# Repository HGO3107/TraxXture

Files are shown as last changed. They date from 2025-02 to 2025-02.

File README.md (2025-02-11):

# 🚀 TaxXture – The Tracker with Capturing Features
A tracking device with **remote interior capturing capabilty**

## 🔥 Features  
- **Real-time location tracking** – Get your vehicle’s location on demand  
- **Motion sensing & speed monitoring** – Know when your vehicle is on the move  
- **Battery Backup and health monitoring** – Keep track of power levels  
- **Remote interior capturing** – Snap image of your vehicle’s interior when needed  
- **Offline storage** – Data backup, even without an internet connection  
- **Reverse polarity protection** – To ensure the device does not get affected should incase the vehicle pollarity is mistakenly swapped  

## 🏗️ Project Structure  
📂 **Main Board** – The brains of the operation
📂 **Cam-Interconnect Board** – The bridge between the camera and the system  
📂 **Rendered Images** – Stunning visuals of the design  

## 🔧 Main Board – What's Inside?  
The **Main Board** packs all the essentials:  
✅ **Microcontroller, sensors, and actuator circuitry**  
✅ **LVDS driver/receiver port** – Ensures **3-5m** long-distance camera communication  

## 📸 Cam-Interconnect Board  
This board connects the camera to the system using:  
✅ **LVDS to SPI converter**  
✅ **Camera port connector**  

## 🚧 Disclaimer; Work in Progress (Status: **DRAFT** 🚀)  
Still some work to do, Below are what I could think of, you can pick it up from here if insterested:  

🔲 **Generate BOM & Fabrication files**  
🔲 **Review schematics & PCB layouts**  
🔲 **Complete the Cam-Interconnect Board:**  
   - PCB layout  
   - Electrical Rule Check (ERC) & Design Rule Check (DRC)  
🔲 **Finalize the enclosure design** (Done in FreeCAD but needs tweaks for connectors)  

## 📷 Main Board Images  

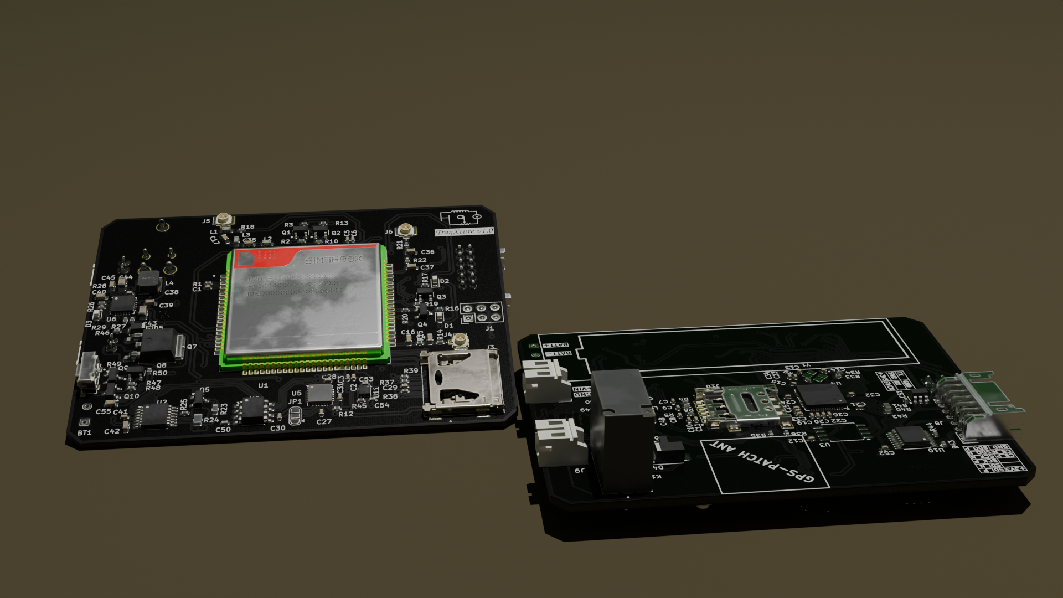
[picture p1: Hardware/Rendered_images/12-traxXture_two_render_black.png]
Main Board


[📄 View Documentation](Hardware/Main-Board/TraxXturE_board.pdf)

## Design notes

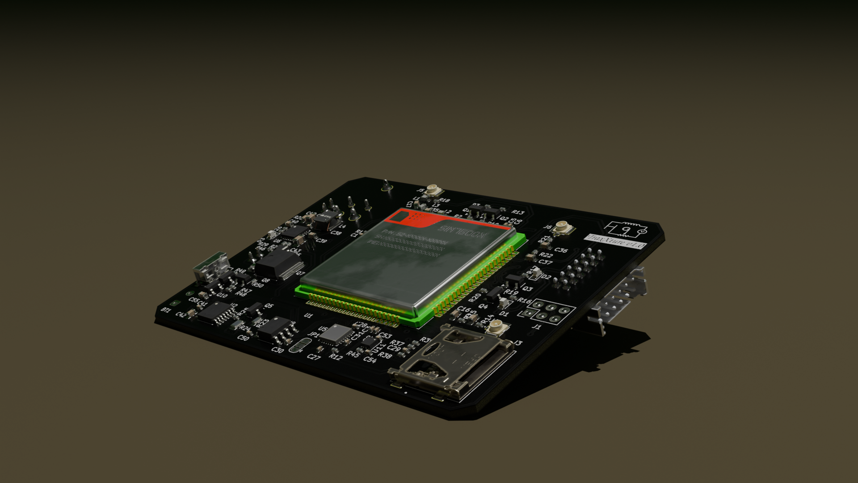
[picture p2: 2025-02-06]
Hardware/Rendered_images/10-traxXture_render_black.png

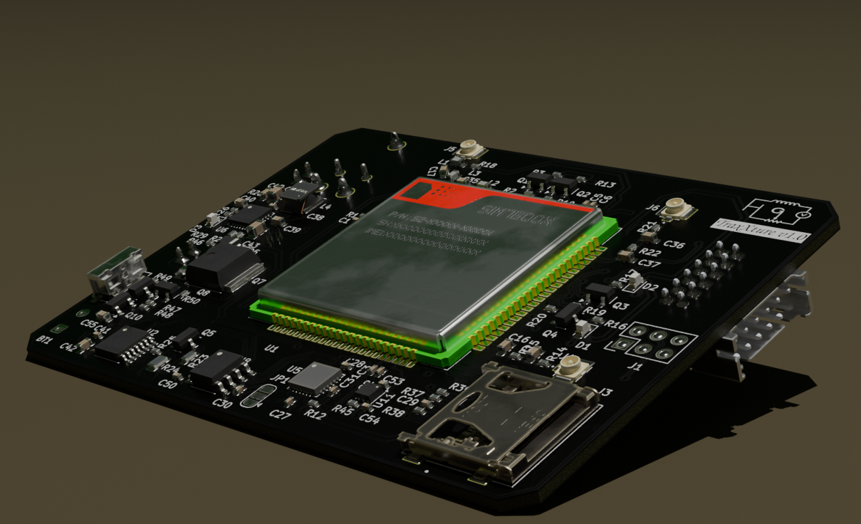
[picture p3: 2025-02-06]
Hardware/Rendered_images/11-traxXture_render_black_crop.png

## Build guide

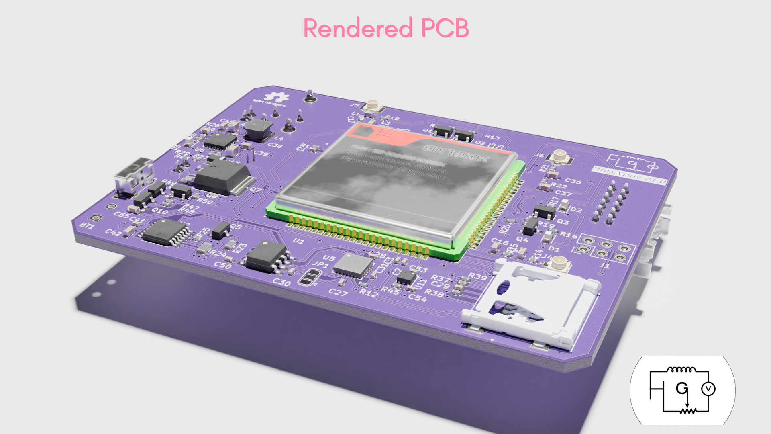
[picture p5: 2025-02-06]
Hardware/Rendered_images/Purple_soldermask.png

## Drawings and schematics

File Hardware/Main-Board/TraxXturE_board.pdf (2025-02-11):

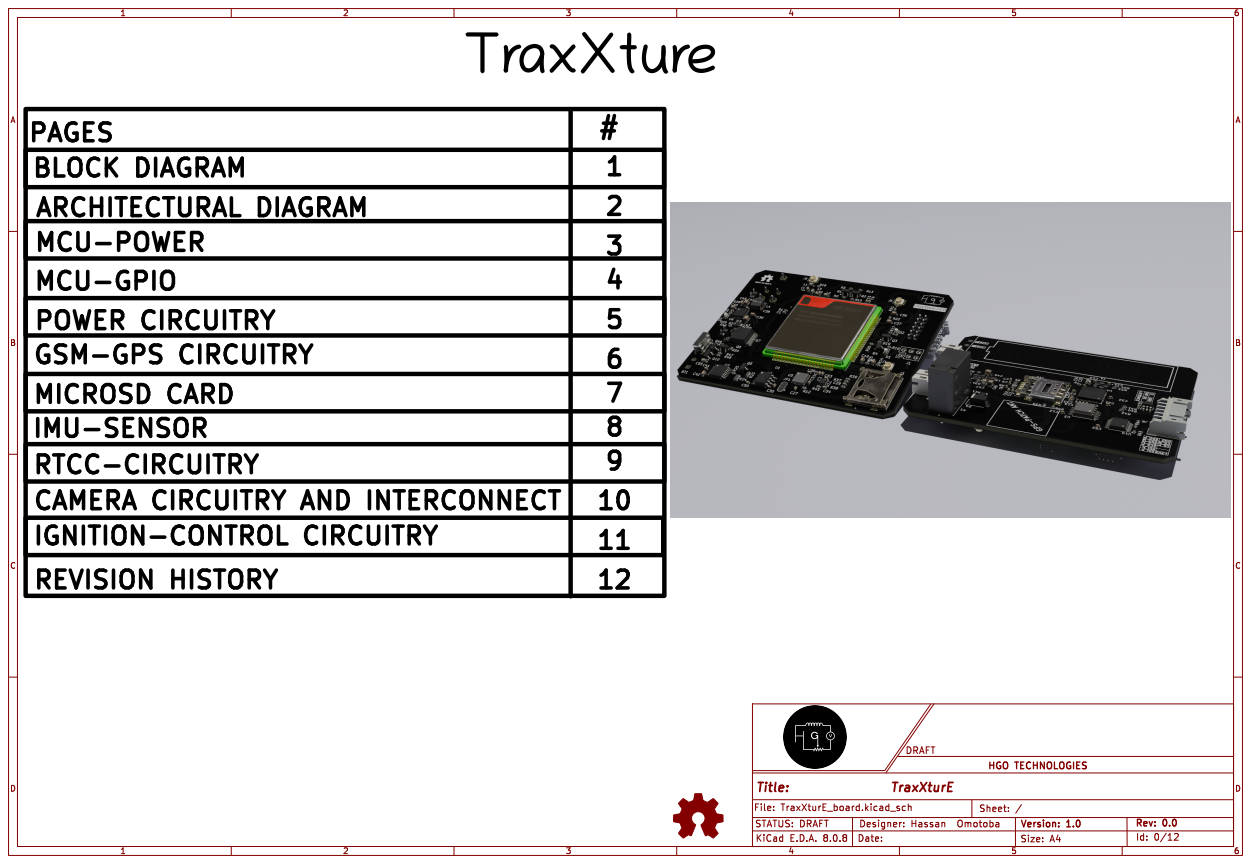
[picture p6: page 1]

MCU-GPIO
POWER CIRCUITRY
GSM-GPS CIRCUITRY | | 6
MICROSD CARD

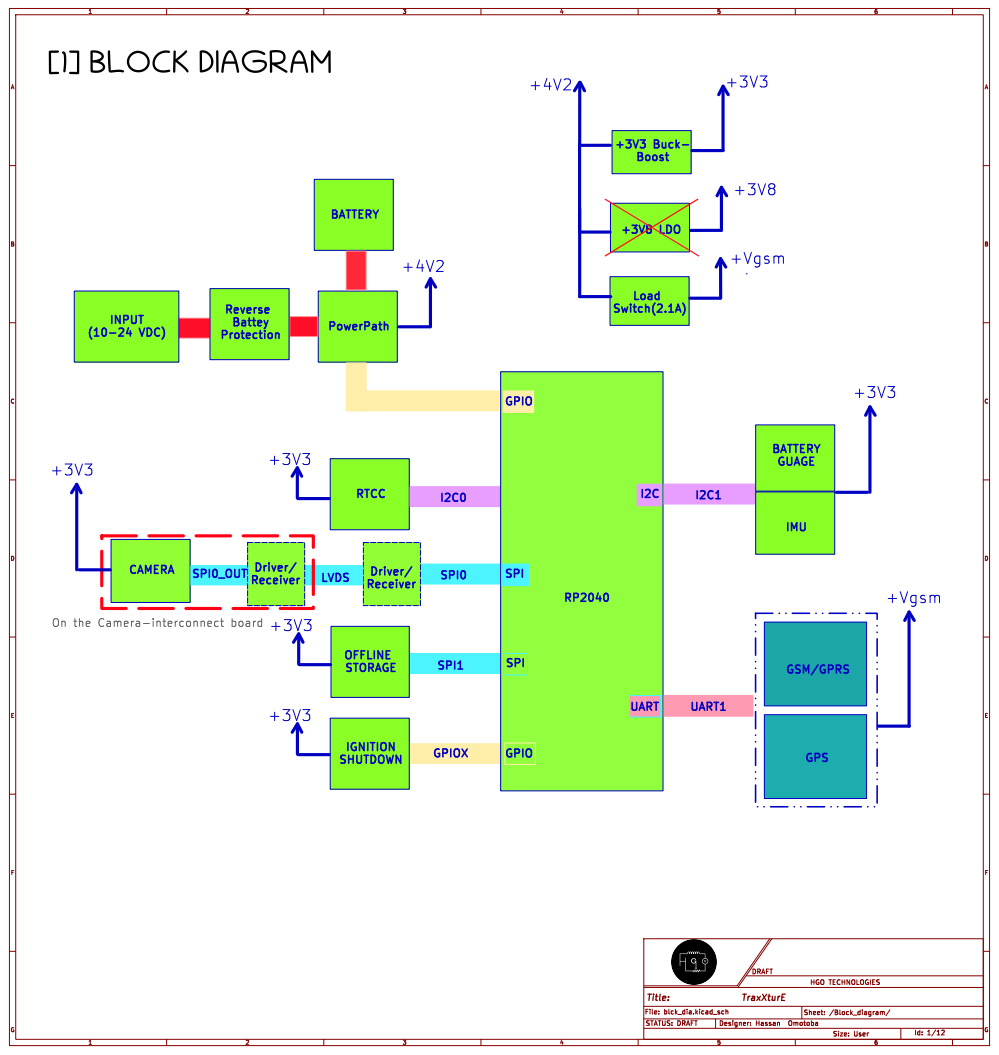
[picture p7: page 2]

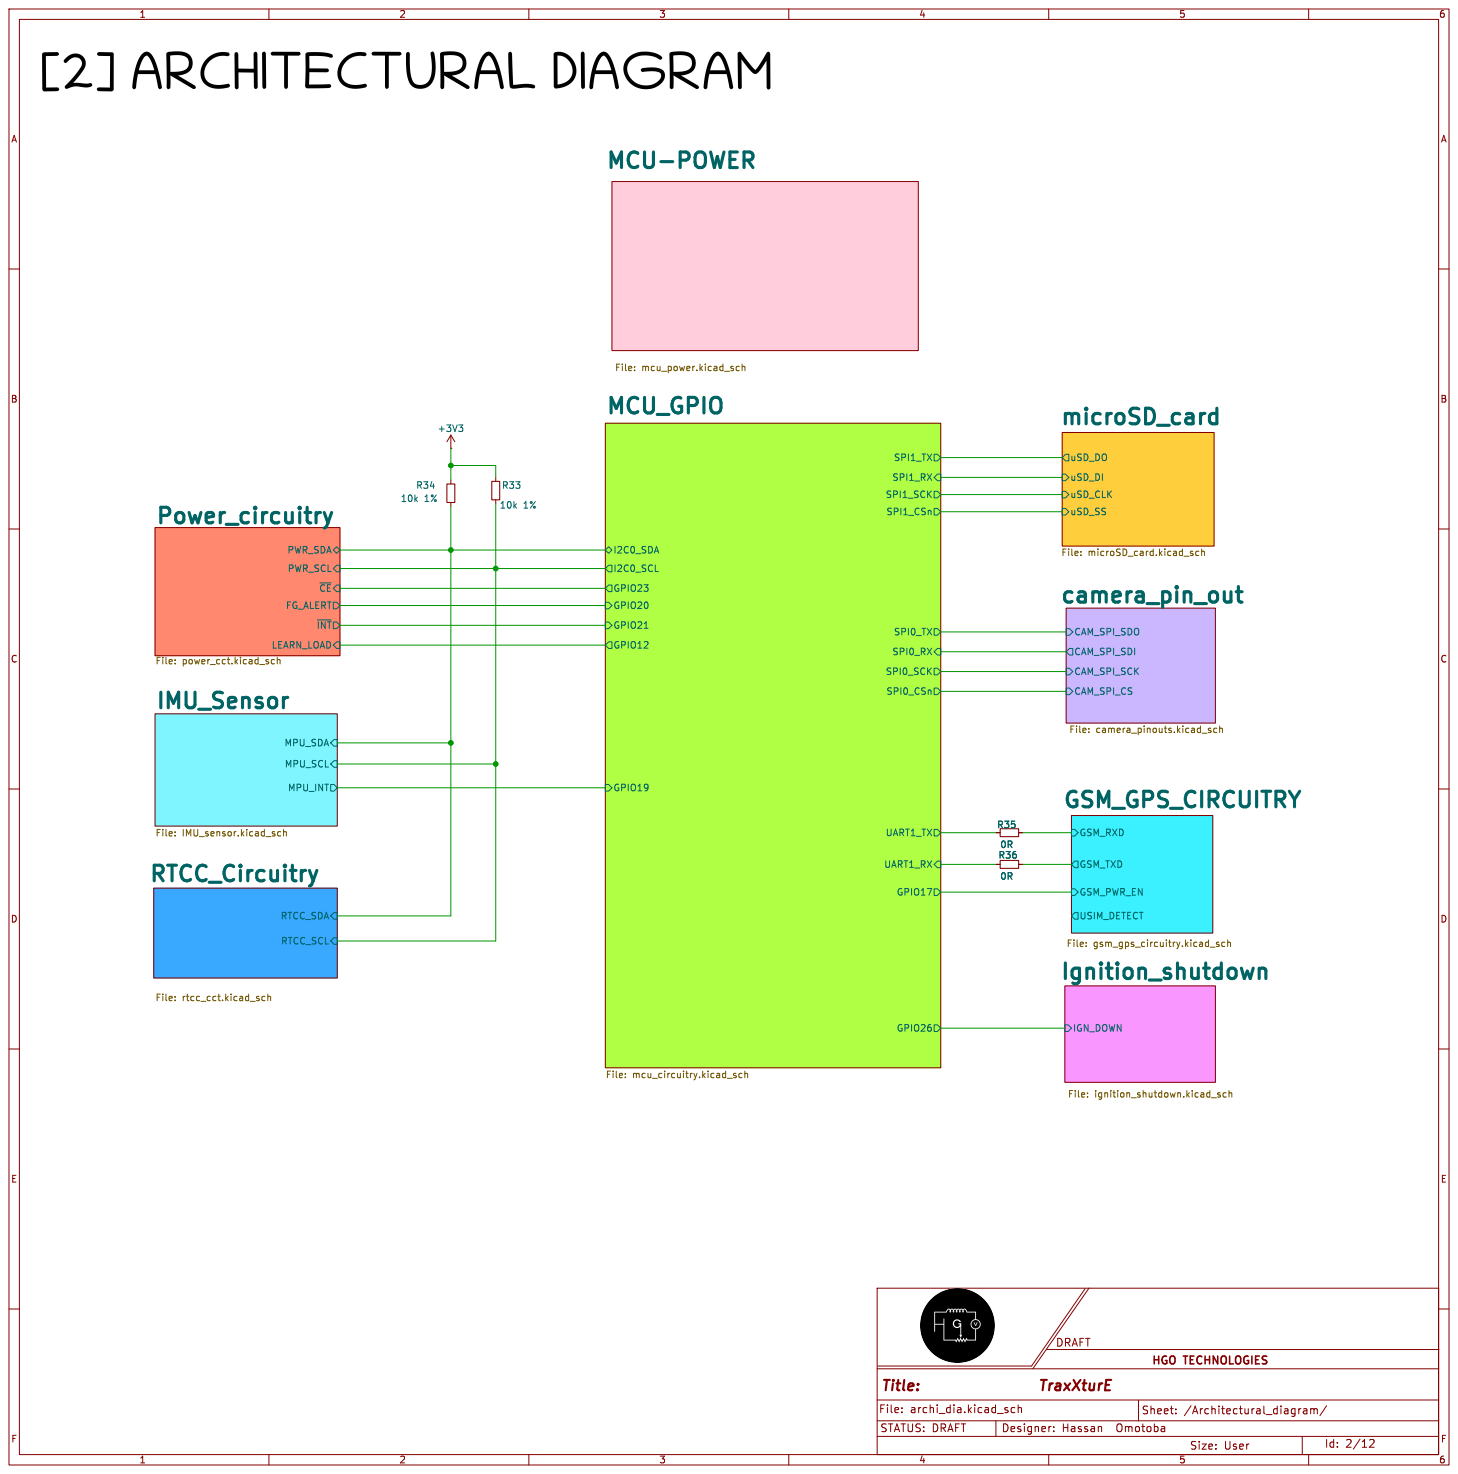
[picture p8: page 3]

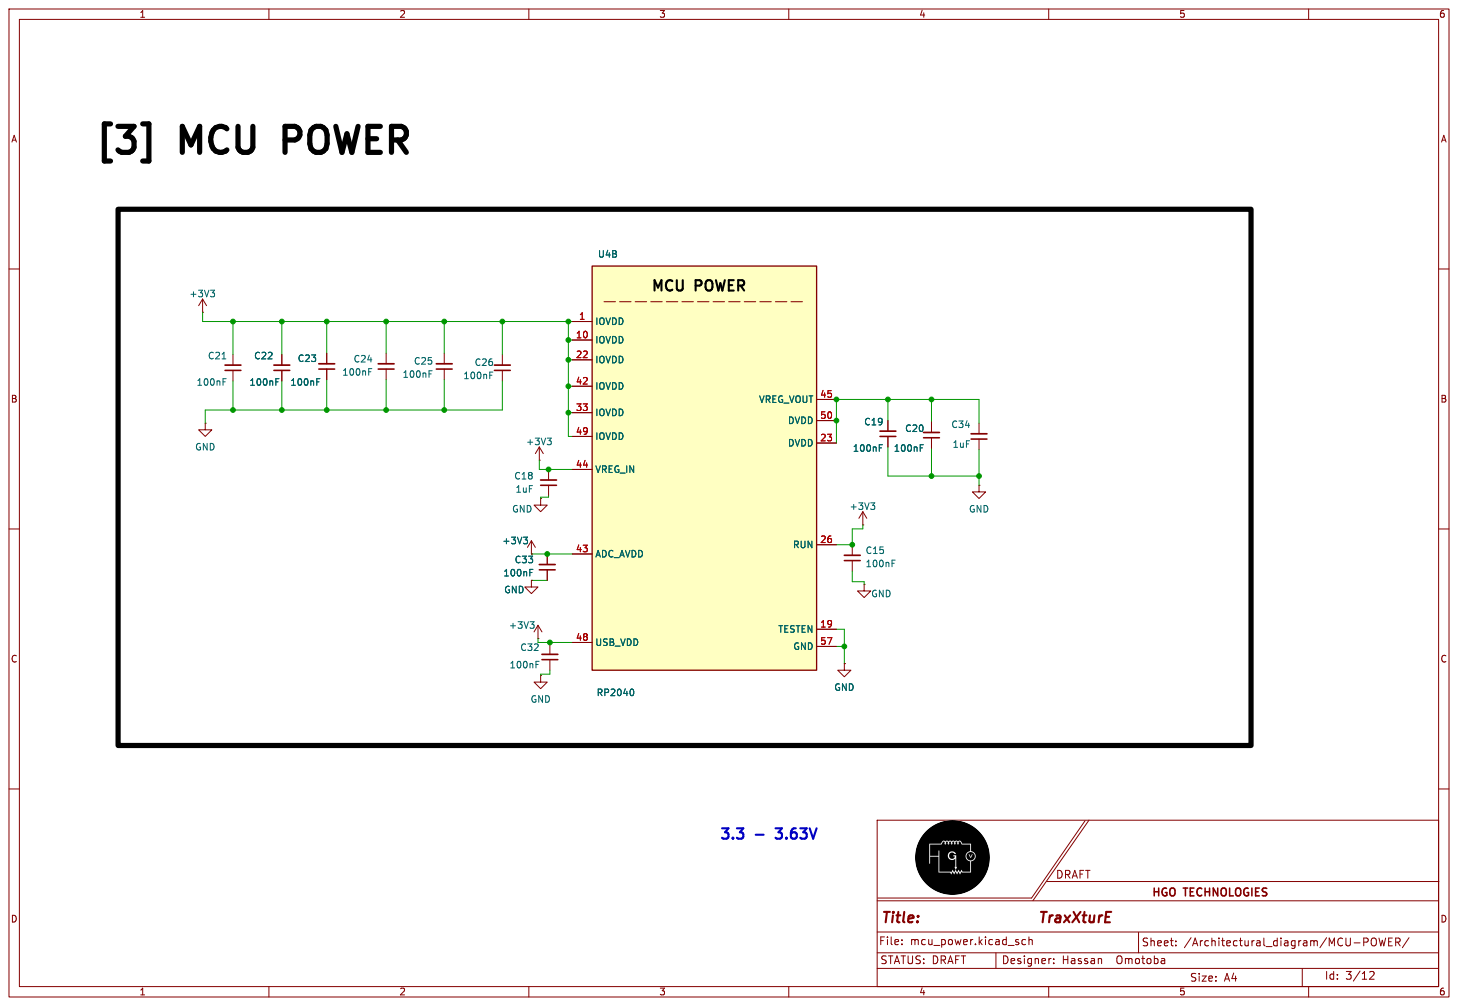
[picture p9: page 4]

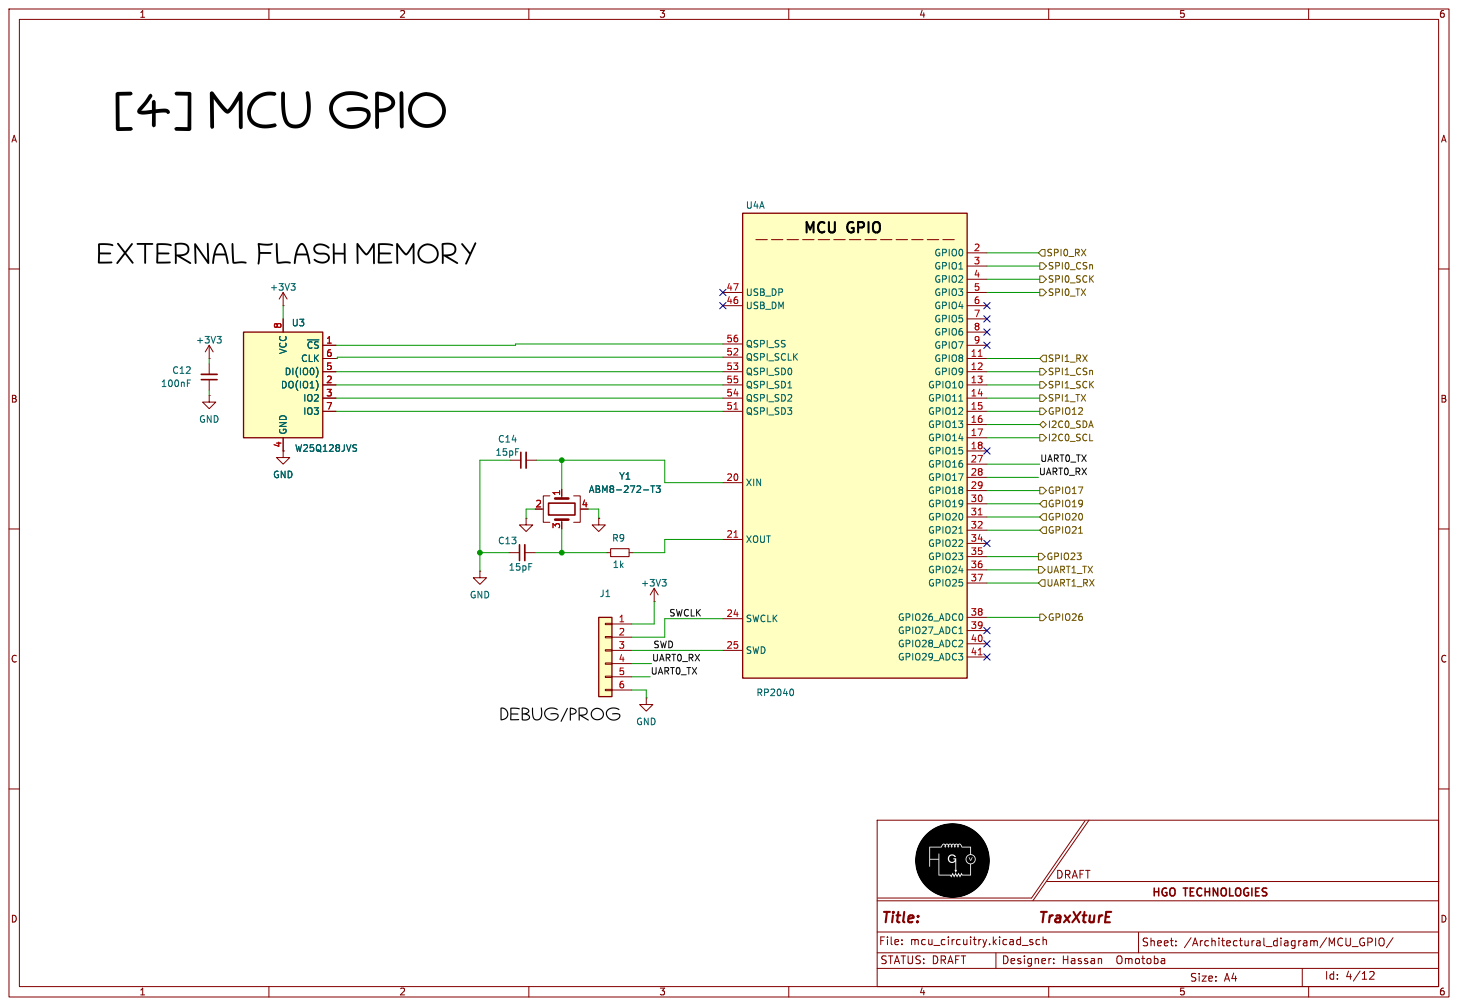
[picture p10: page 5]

SWCLK EXTERNAL FLASH MEMORY

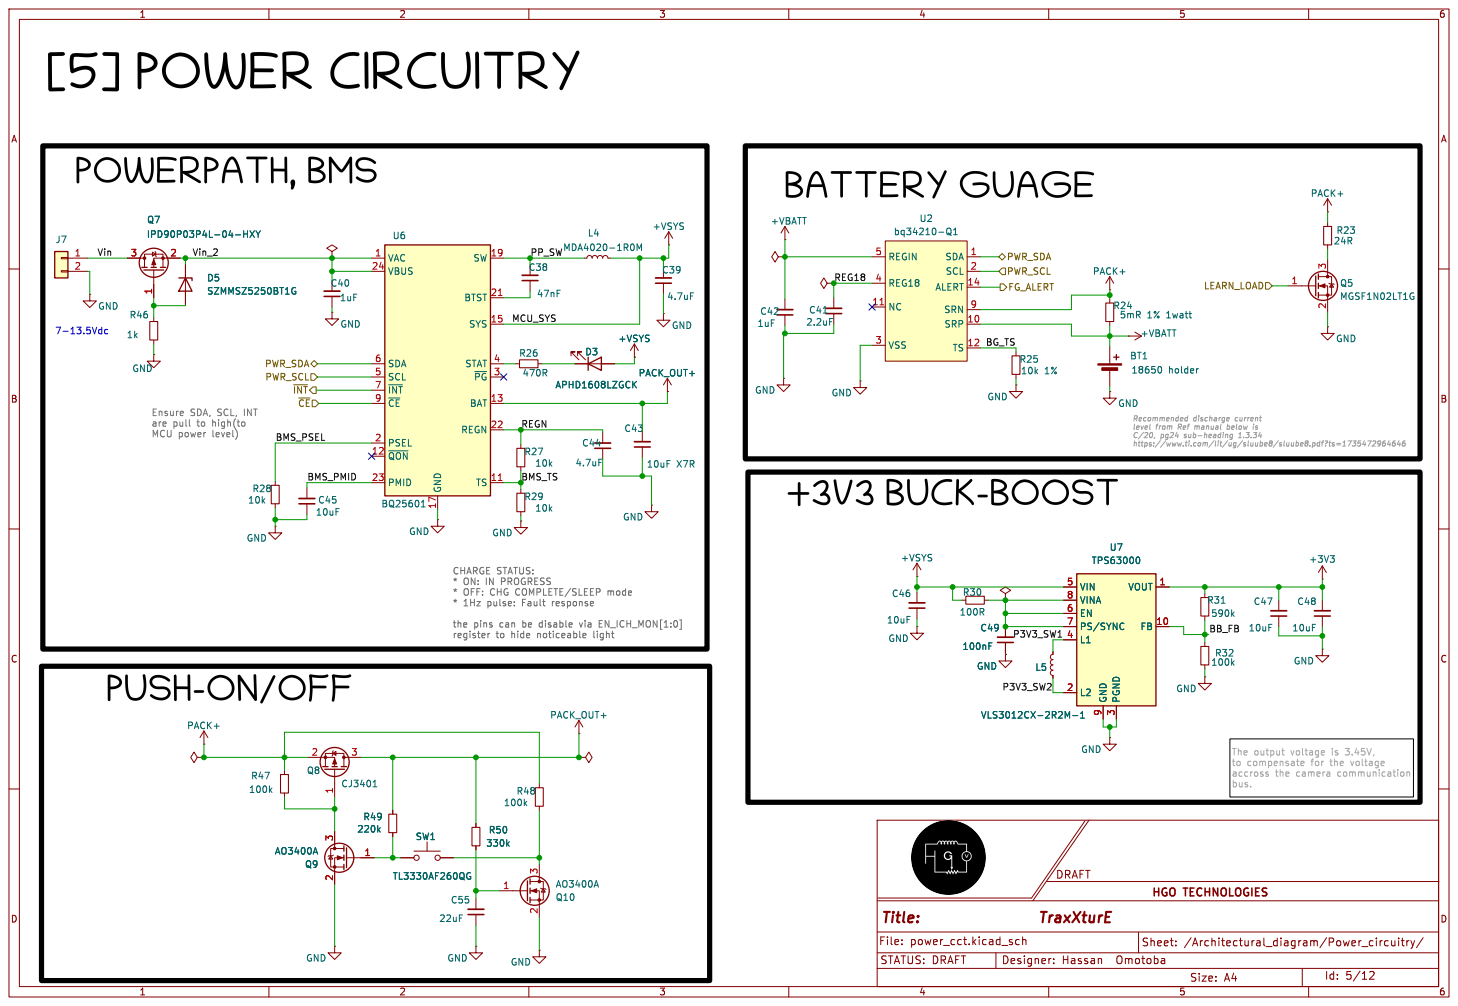
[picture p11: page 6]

https://www.ti.com/lit/ug/sluube8/sluube8.pdf?ts=1735472964646 [5] POWERCIRCUITRY
+VBATT R48

are pull to high(to MCU power level) 7-13.5Vdc POWERPATH,BMS

Ensure SDA, SCL, INT

CHARGE STATUS: * ON: IN PROGRESS
PACK_OUT+ GND

* OFF: CHG COMPLETE/SLEEP mode
* 1Hz pulse: Fault response

the pins can be disable via EN_ICH_MON[1:0]

bus. PUSH-ON/OFF

The output voltage is 3.45V,
accross the camera communication

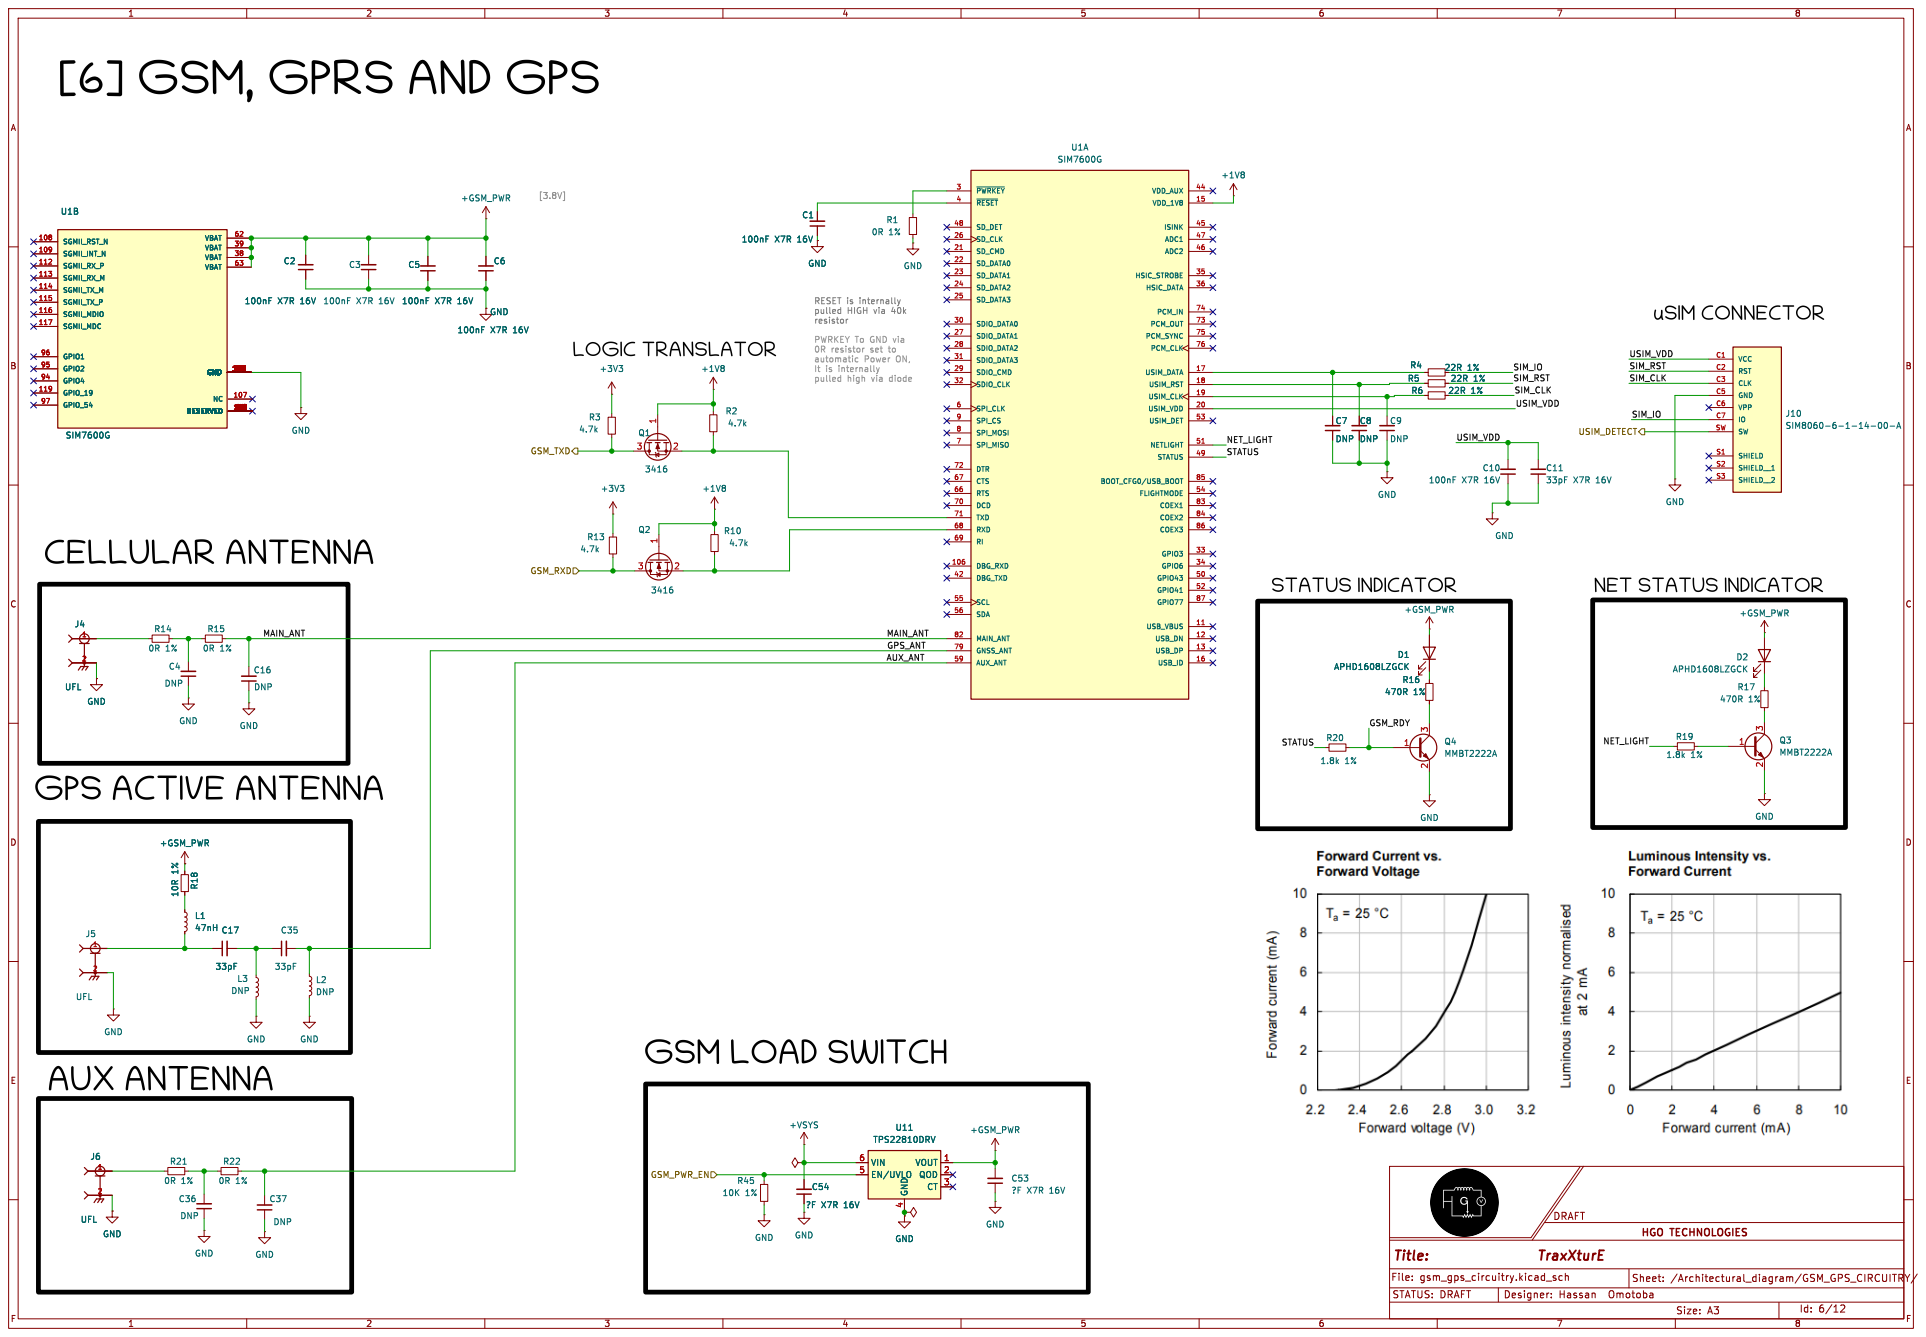
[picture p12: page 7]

pulled high via diode RESET is internally
pulled HIGH via 40k

PWRKEY To GND via
It is internally

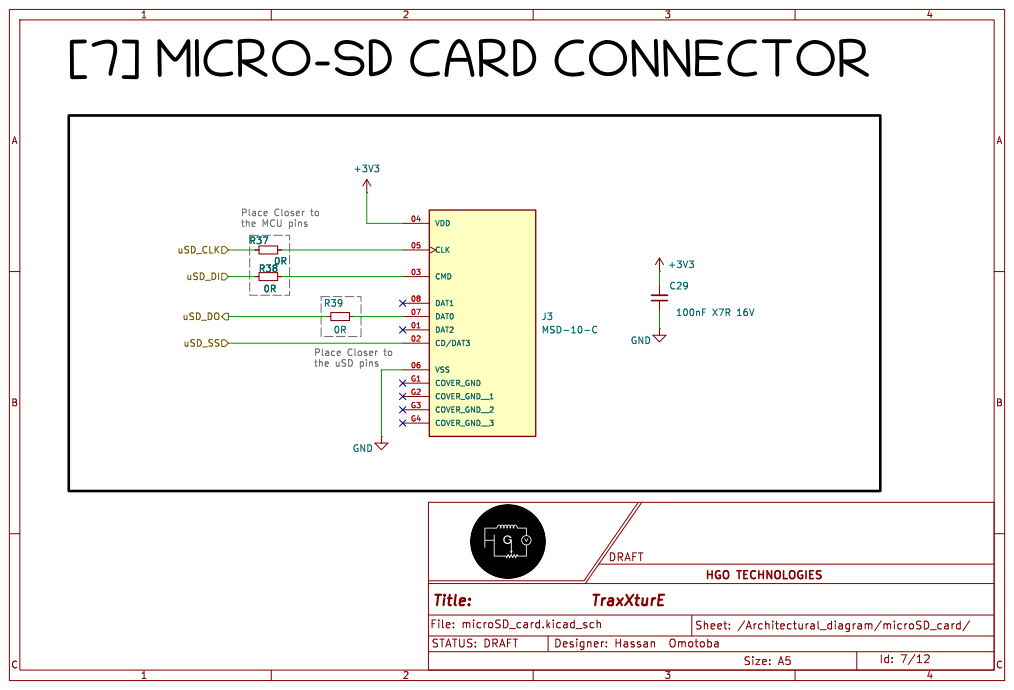
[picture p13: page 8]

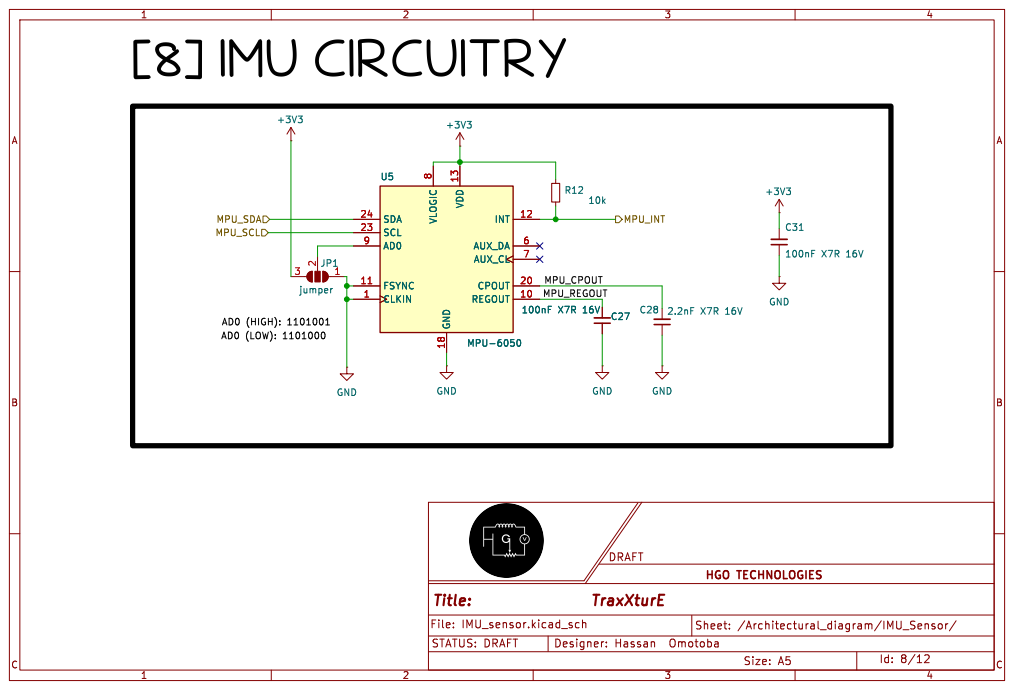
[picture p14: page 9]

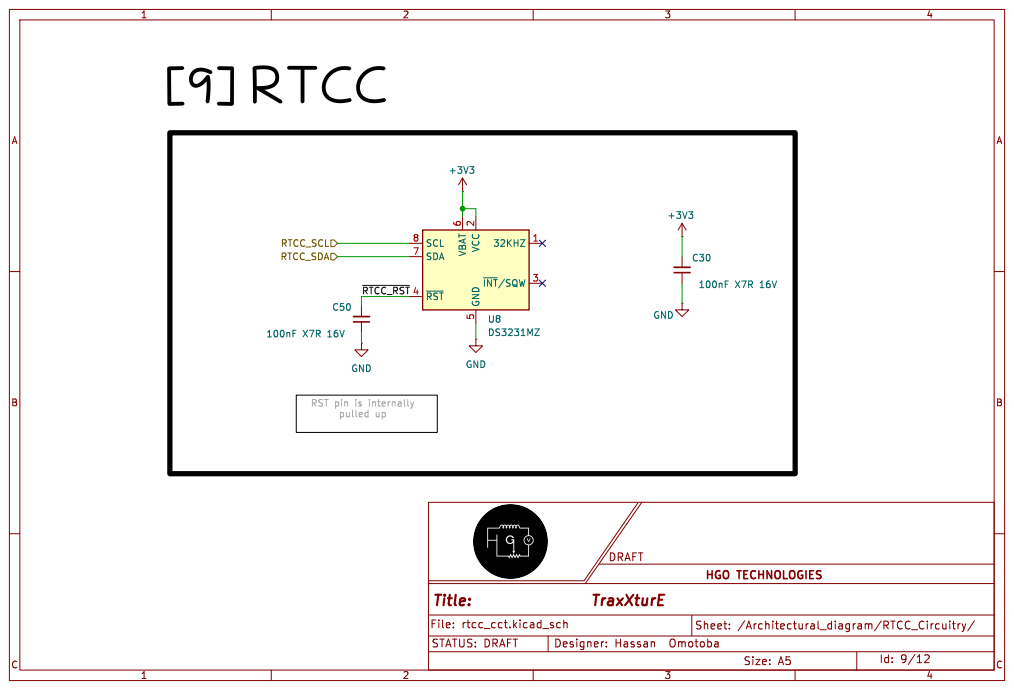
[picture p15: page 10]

RST pin is internally
pulled up

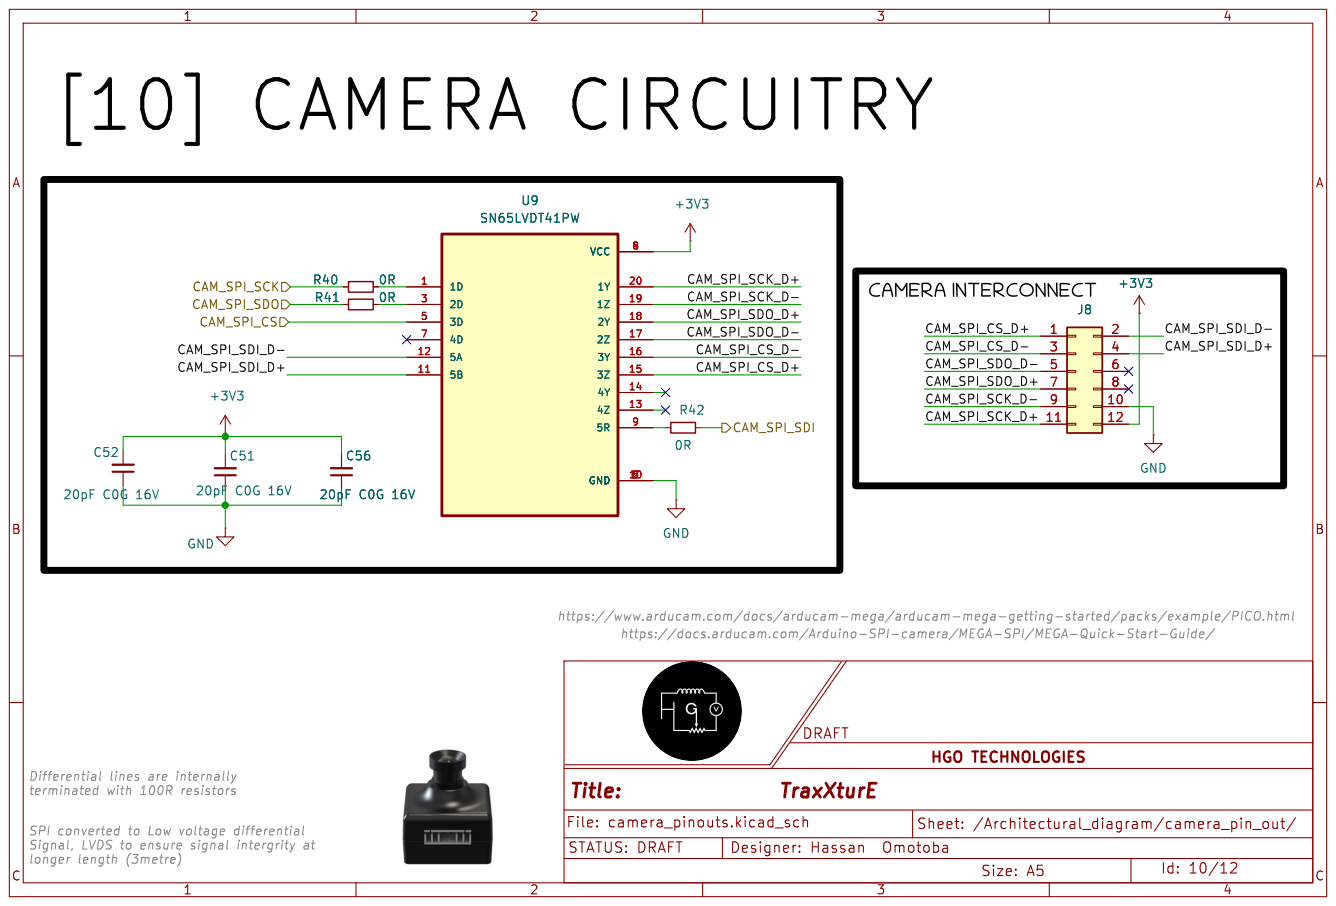
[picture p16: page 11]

https://www.arducam.com/docs/arducam-mega/arducam-mega-getting-started/packs/example/PICO.html

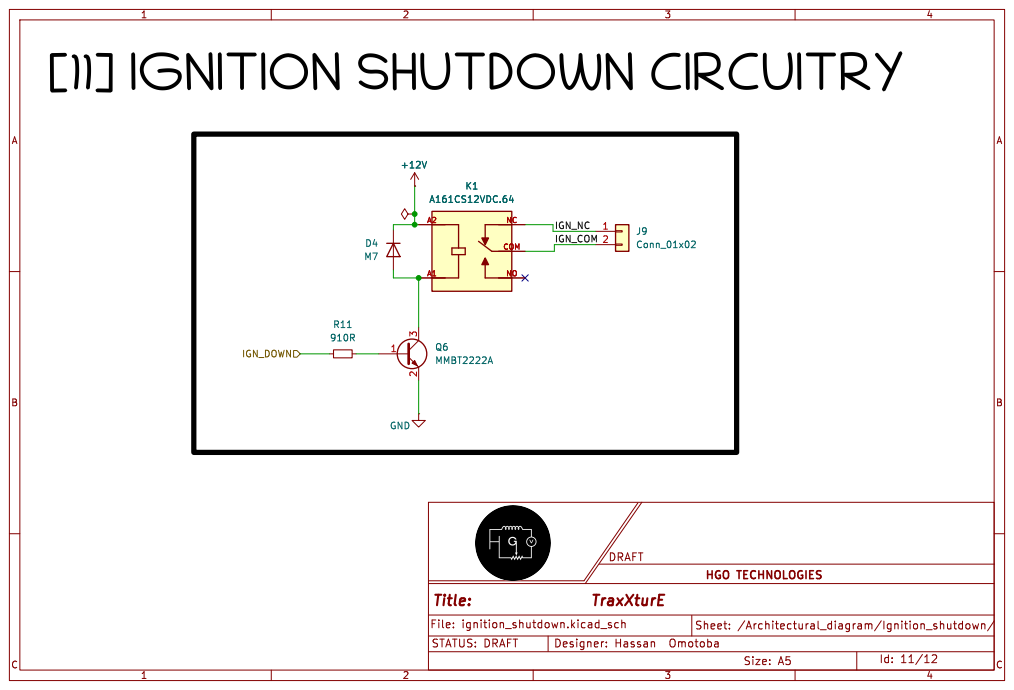
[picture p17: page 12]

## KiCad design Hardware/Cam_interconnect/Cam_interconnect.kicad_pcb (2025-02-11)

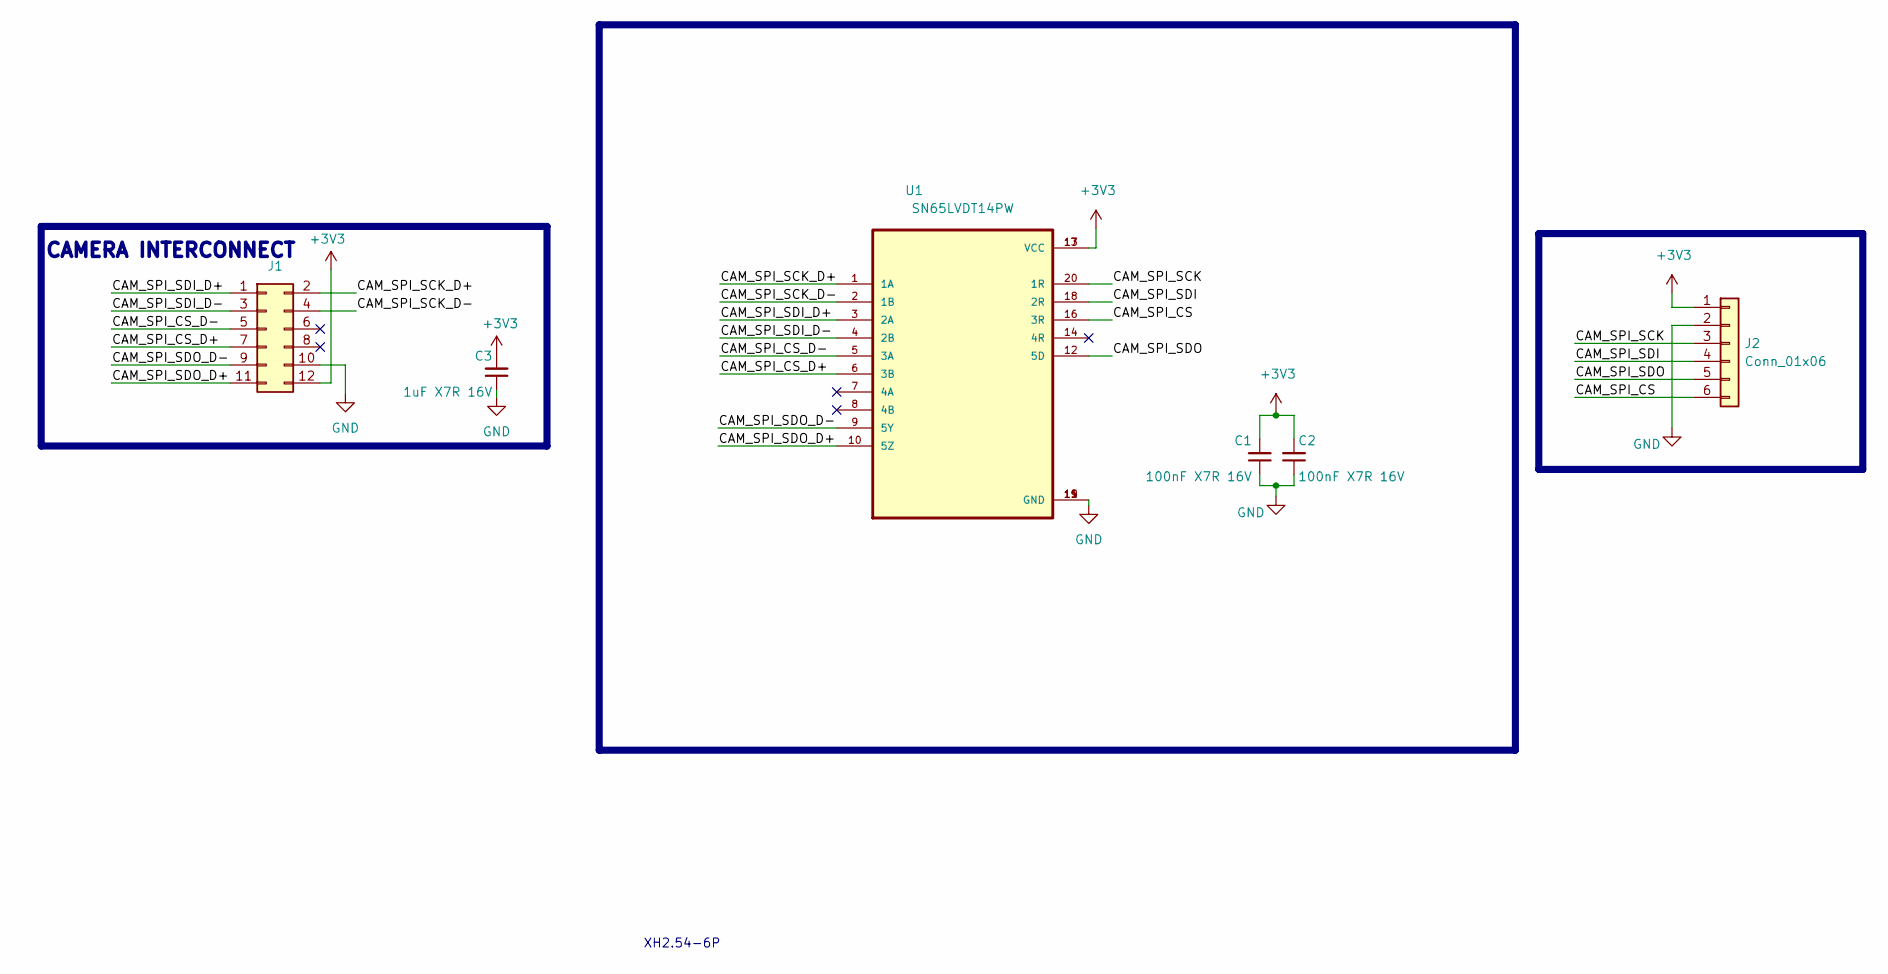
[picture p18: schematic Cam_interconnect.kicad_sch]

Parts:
C1, C2: 100nF X7R 16V; C_0402_1005Metric
C3: 1uF X7R 16V; C_0402_1005Metric
J1: Conn_02x06_Odd_Even; JST_PHD_S12B-PHDSS_2x06_P2.00mm_Horizontal
J2: Conn_01x06; PinSocket_1x06_P2.54mm_Vertical_SMD_Pin1Right
U1: SN65LVDT14PW; SOP65P640X120-20N

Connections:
+3V3: C1.2, C2.2, C3.2, J1.12, J2.1, U1.13 (VCC), U1.17 (VCC)
/CAM_SPI_CS: J2.6, U1.16 (3R)
/CAM_SPI_CS_D+: J1.7, U1.6 (3B)
/CAM_SPI_CS_D-: J1.5, U1.5 (3A)
/CAM_SPI_SCK: J2.3, U1.20 (1R)
/CAM_SPI_SCK_D+: J1.2, U1.1 (1A)
/CAM_SPI_SCK_D-: J1.4, U1.2 (1B)
/CAM_SPI_SDI: J2.4, U1.18 (2R)
/CAM_SPI_SDI_D+: J1.1, U1.3 (2A)
/CAM_SPI_SDI_D-: J1.3, U1.4 (2B)
/CAM_SPI_SDO: J2.5, U1.12 (5D)
/CAM_SPI_SDO_D+: J1.11, U1.10 (5Z)
/CAM_SPI_SDO_D-: J1.9, U1.9 (5Y)
GND: C1.1, C2.1, C3.1, J1.10, J2.2, U1.11 (GND), U1.15 (GND), U1.19 (GND)

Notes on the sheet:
XH2.54-6P
CAMERA INTERCONNECT

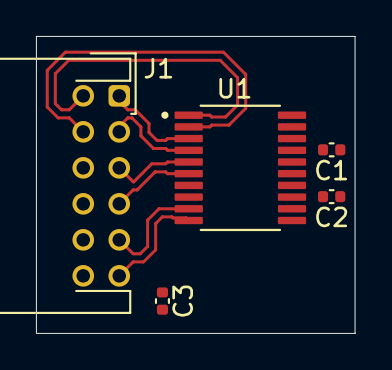
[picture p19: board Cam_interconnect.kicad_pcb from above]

Board: 4 copper layers, 17.7 x 16.5 mm, 6 parts (1 on the bottom side), 14 nets.

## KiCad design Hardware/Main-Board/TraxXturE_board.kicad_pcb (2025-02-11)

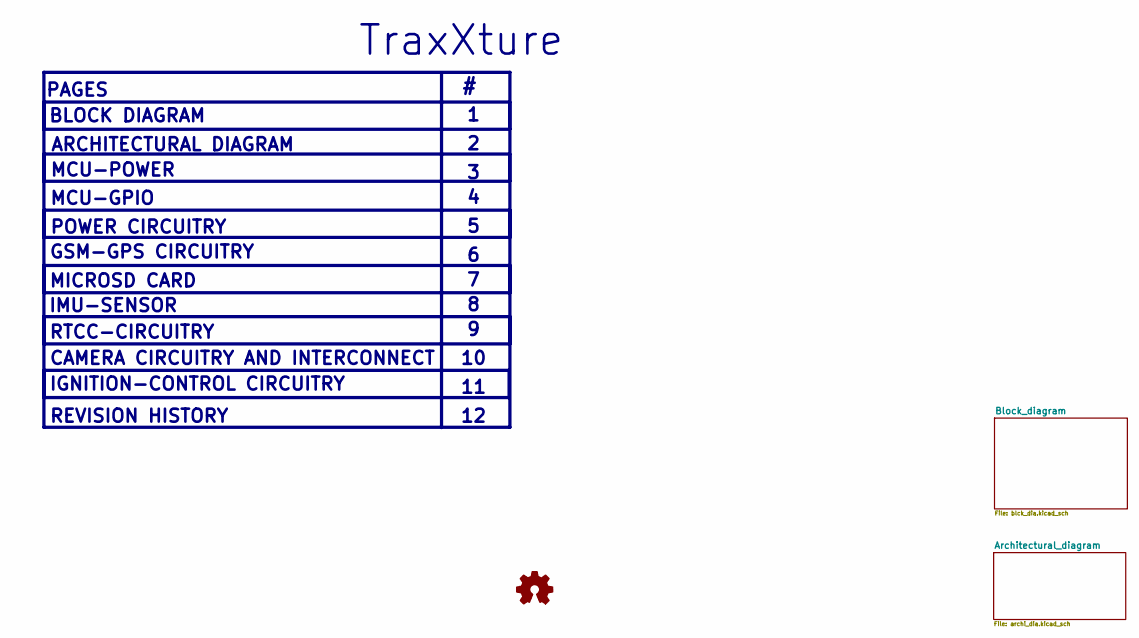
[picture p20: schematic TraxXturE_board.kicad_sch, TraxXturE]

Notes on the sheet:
IMU-SENSOR
MCU-POWER
MICROSD CARD
ARCHITECTURAL DIAGRAM
PAGES
RTCC-CIRCUITRY
CAMERA CIRCUITRY AND INTERCONNECT
BLOCK DIAGRAM
POWER CIRCUITRY
GSM-GPS CIRCUITRY
REVISION HISTORY
MCU-GPIO
IGNITION-CONTROL CIRCUITRY
TraxXture

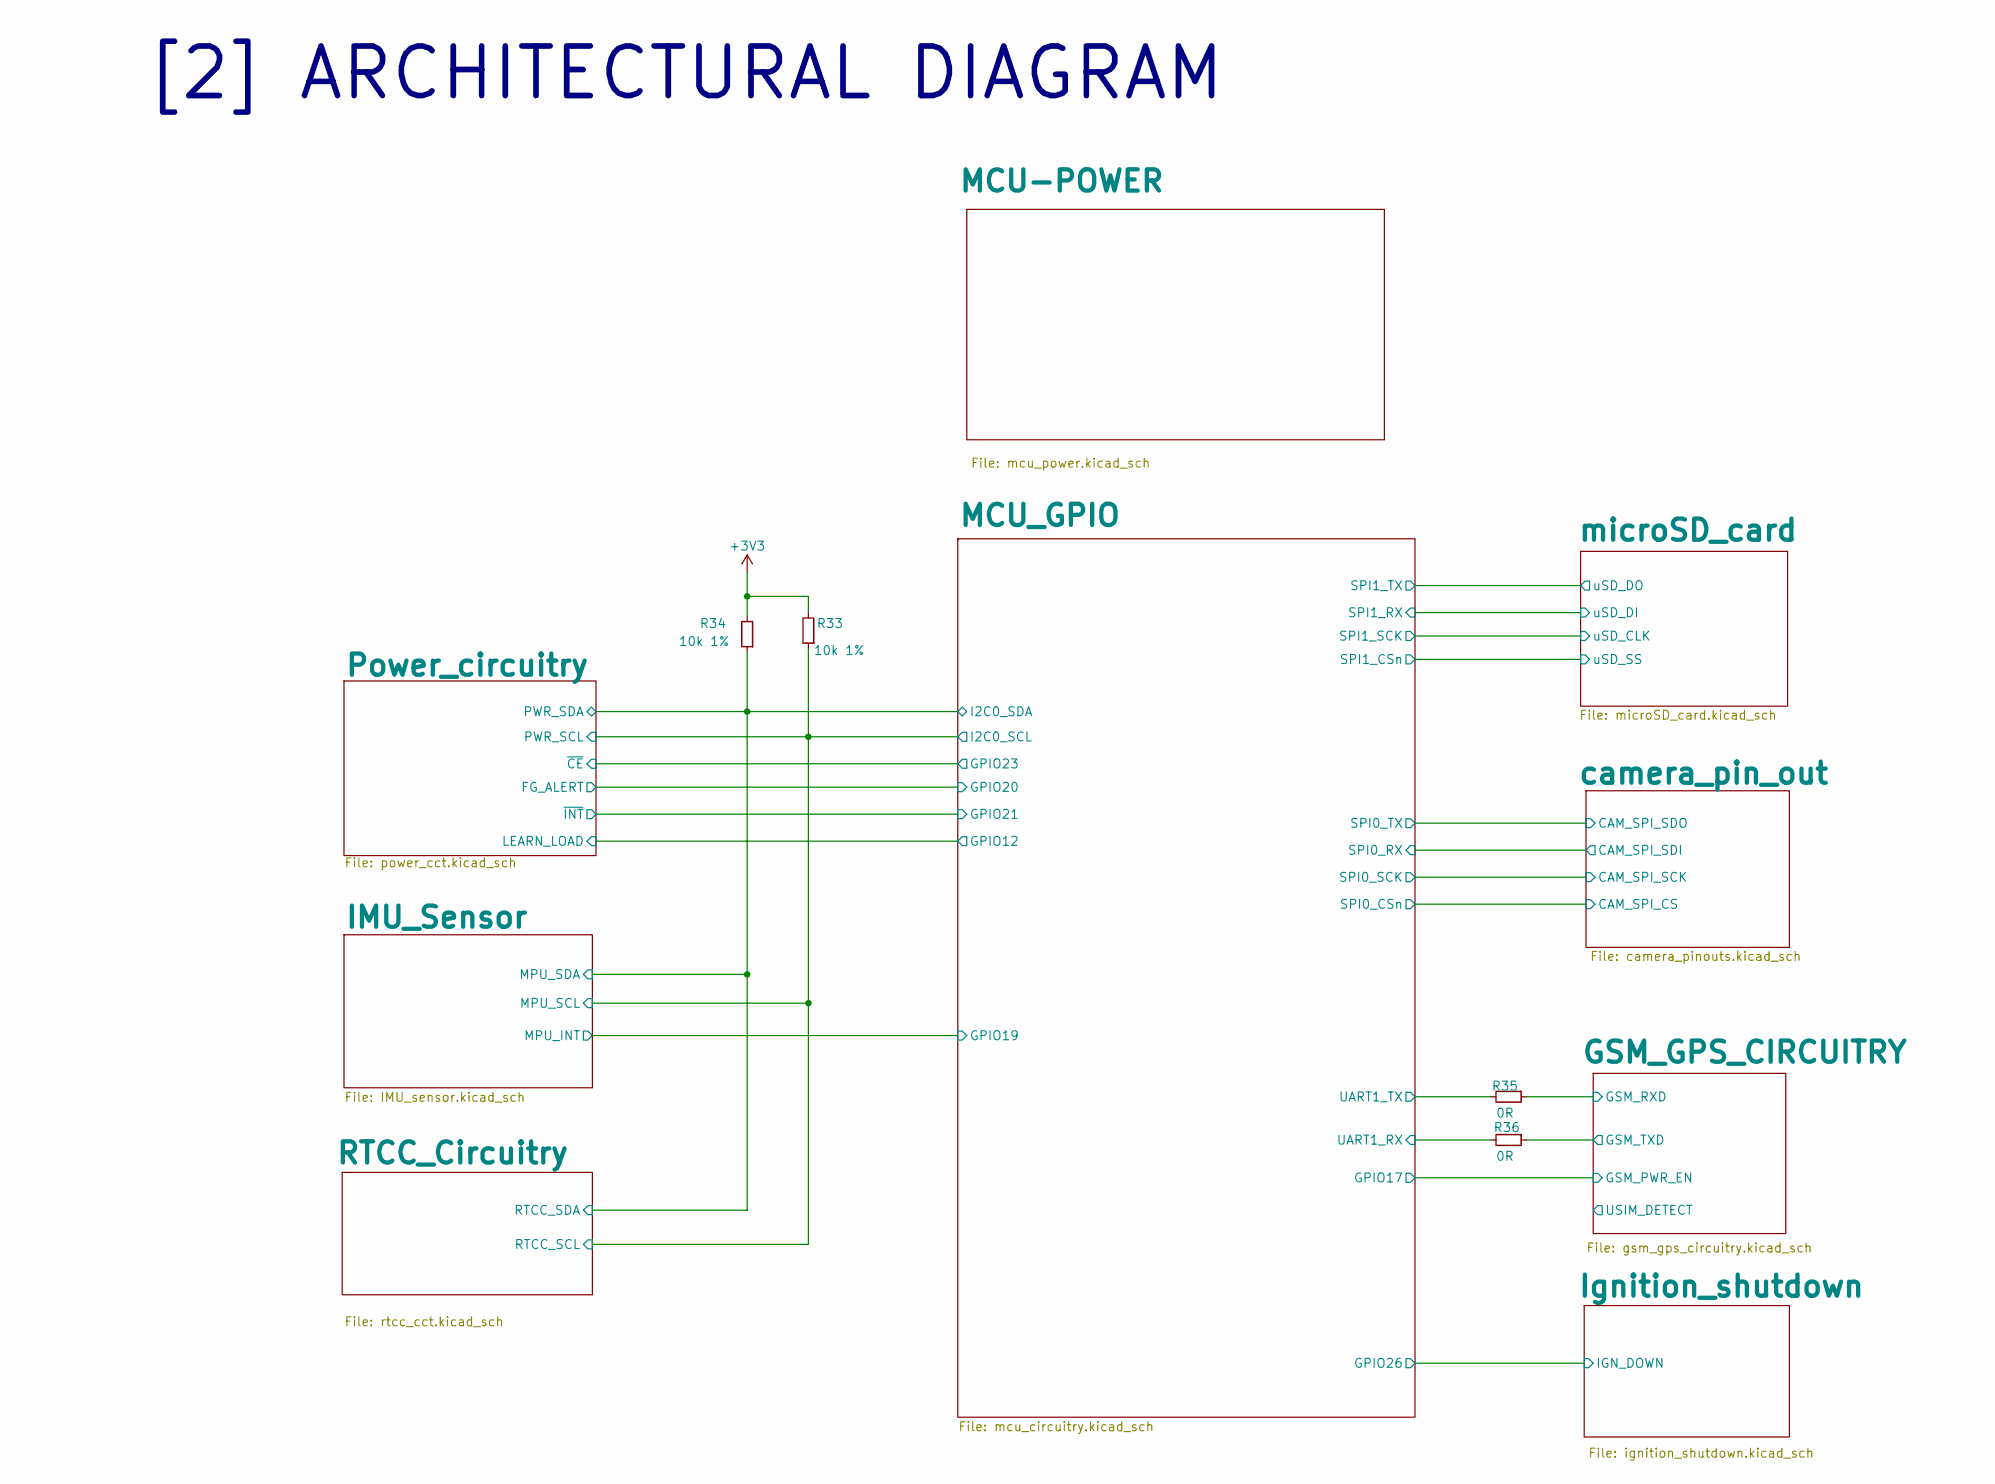
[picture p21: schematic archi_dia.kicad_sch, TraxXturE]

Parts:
R33, R34: 10k 1%; R_0402_1005Metric
R35, R36: 0R; R_0402_1005Metric

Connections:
+3V3: R33.2, R34.2; also elsewhere on the board
/Architectural_diagram/GSM_GPS_CIRCUITRY/GSM_RXD: R35.1; also elsewhere on the board
/Architectural_diagram/GSM_GPS_CIRCUITRY/GSM_TXD: R36.1; also elsewhere on the board
/Architectural_diagram/IMU_Sensor/MPU_SCL: R33.1; also elsewhere on the board
/Architectural_diagram/IMU_Sensor/MPU_SDA: R34.1; also elsewhere on the board
/Architectural_diagram/MCU_GPIO/UART1_RX: R36.2; also elsewhere on the board
/Architectural_diagram/MCU_GPIO/UART1_TX: R35.2; also elsewhere on the board

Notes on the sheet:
[2] ARCHITECTURAL DIAGRAM

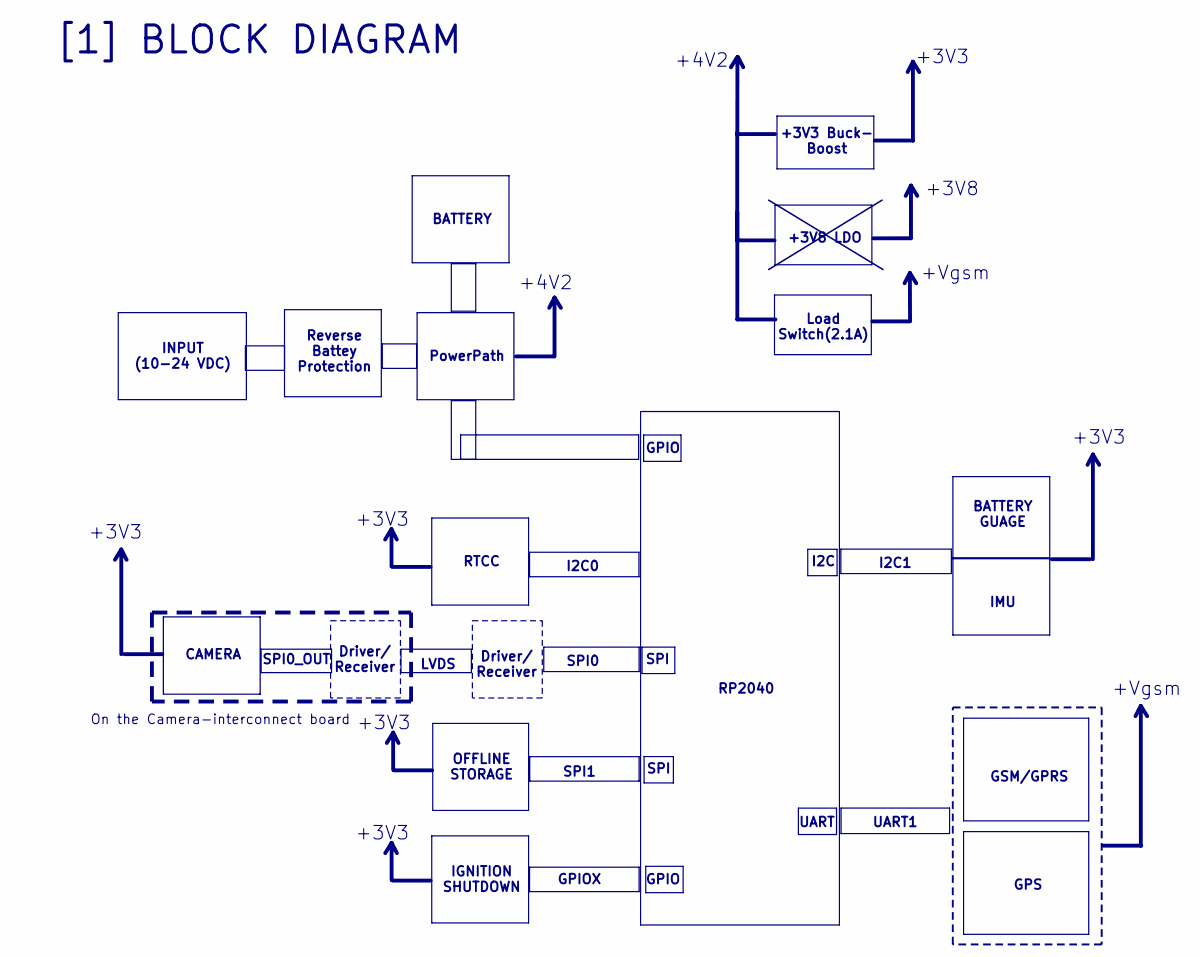
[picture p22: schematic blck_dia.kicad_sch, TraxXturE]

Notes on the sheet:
SPI0_OUT
+3V3
SPI
I2C
OFFLINE STORAGE
+3V8
I2C0
GPIO
UART
BATTERY
CAMERA
GSM/GPRS
INPUT (10-24 VDC)
Driver/ Receiver
I2C1
+3V8 LDO
IGNITION SHUTDOWN
BATTERY GUAGE
PowerPath
LVDS
SPI1
+3V3 Buck- Boost
SPI0
Reverse Battey Protection
+4V2
RTCC
On the Camera-interconnect board
+Vgsm
UART1
[1] BLOCK DIAGRAM
GPS
IMU
RP2040
GPIOX
Load Switch(2.1A)

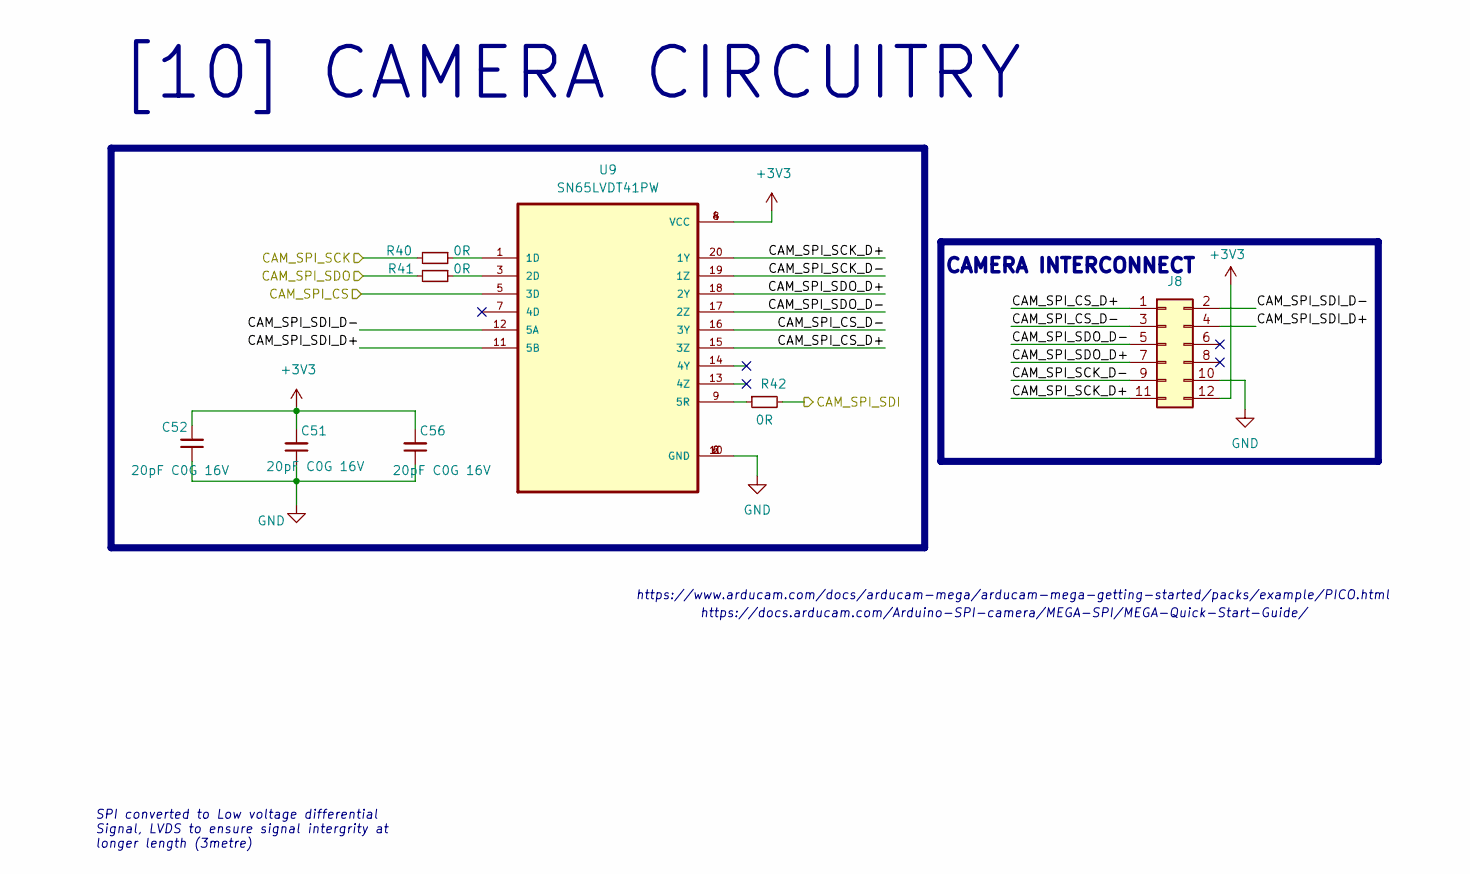
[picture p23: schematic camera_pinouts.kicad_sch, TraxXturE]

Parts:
C51, C52, C56: 20pF C0G 16V; C_0402_1005Metric
J8: Conn_02x06_Odd_Even; JST_PHD_S12B-PHDSS_2x06_P2.00mm_Horizontal
R40, R41, R42: 0R; R_0402_1005Metric
U9: SN65LVDT41PW; SOP65P640X120-20N

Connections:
+3V3: C51.2, C52.2, C56.2, J8.12, U9.4 (VCC), U9.8 (VCC); also elsewhere on the board
/Architectural_diagram/MCU_GPIO/SPI0_CSn: U9.5 (3D); also elsewhere on the board
/Architectural_diagram/MCU_GPIO/SPI0_RX: R42.2; also elsewhere on the board
/Architectural_diagram/MCU_GPIO/SPI0_SCK: R40.2; also elsewhere on the board
/Architectural_diagram/MCU_GPIO/SPI0_TX: R41.2; also elsewhere on the board
/Architectural_diagram/camera_pin_out/CAM_SPI_CS_D+: J8.1, U9.15 (3Z)
/Architectural_diagram/camera_pin_out/CAM_SPI_CS_D-: J8.3, U9.16 (3Y)
/Architectural_diagram/camera_pin_out/CAM_SPI_SCK_D+: J8.11, U9.20 (1Y)
/Architectural_diagram/camera_pin_out/CAM_SPI_SCK_D-: J8.9, U9.19 (1Z)
/Architectural_diagram/camera_pin_out/CAM_SPI_SDI_D+: J8.4, U9.11 (5B)
/Architectural_diagram/camera_pin_out/CAM_SPI_SDI_D-: J8.2, U9.12 (5A)
/Architectural_diagram/camera_pin_out/CAM_SPI_SDO_D+: J8.7, U9.18 (2Y)
/Architectural_diagram/camera_pin_out/CAM_SPI_SDO_D-: J8.5, U9.17 (2Z)
GND: C51.1, C52.1, C56.1, J8.10, U9.2 (GND), U9.6 (GND), U9.10 (GND); also elsewhere on the board
unnamed: R40.1, U9.1 (1D)
unnamed: R41.1, U9.3 (2D)
unnamed: R42.1, U9.9 (5R)

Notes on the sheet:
https://www.arducam.com/docs/arducam-mega/arducam-mega-getting-started/packs/example/PICO.html
SPI converted to Low voltage differential Signal, LVDS to ensure signal intergrity at longer length (3metre)
https://docs.arducam.com/Arduino-SPI-camera/MEGA-SPI/MEGA-Quick-Start-Guide/
CAMERA INTERCONNECT
[10] CAMERA CIRCUITRY

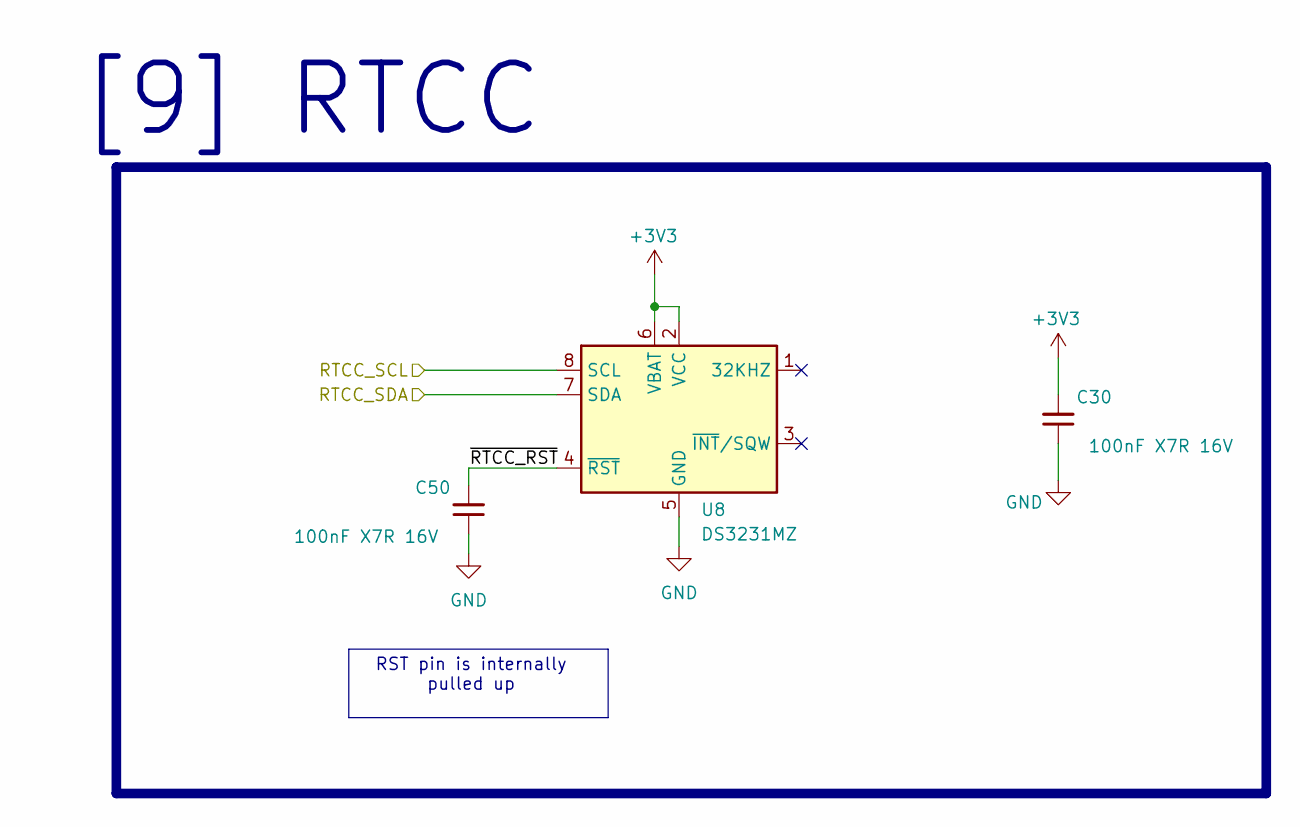
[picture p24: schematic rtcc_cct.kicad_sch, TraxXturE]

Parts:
C30, C50: 100nF X7R 16V; C_0402_1005Metric
U8: DS3231MZ; SOIC-8_3.9x4.9mm_P1.27mm

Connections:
+3V3: C30.2, U8.2 (VCC), U8.6 (VBAT); also elsewhere on the board
/Architectural_diagram/IMU_Sensor/MPU_SCL: U8.8 (SCL); also elsewhere on the board
/Architectural_diagram/IMU_Sensor/MPU_SDA: U8.7 (SDA); also elsewhere on the board
/Architectural_diagram/RTCC_Circuitry/~RTCC_RST: C50.2, U8.4 (~RST)
GND: C30.1, C50.1, U8.5 (GND); also elsewhere on the board

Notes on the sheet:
RST pin is internally pulled up
[9] RTCC

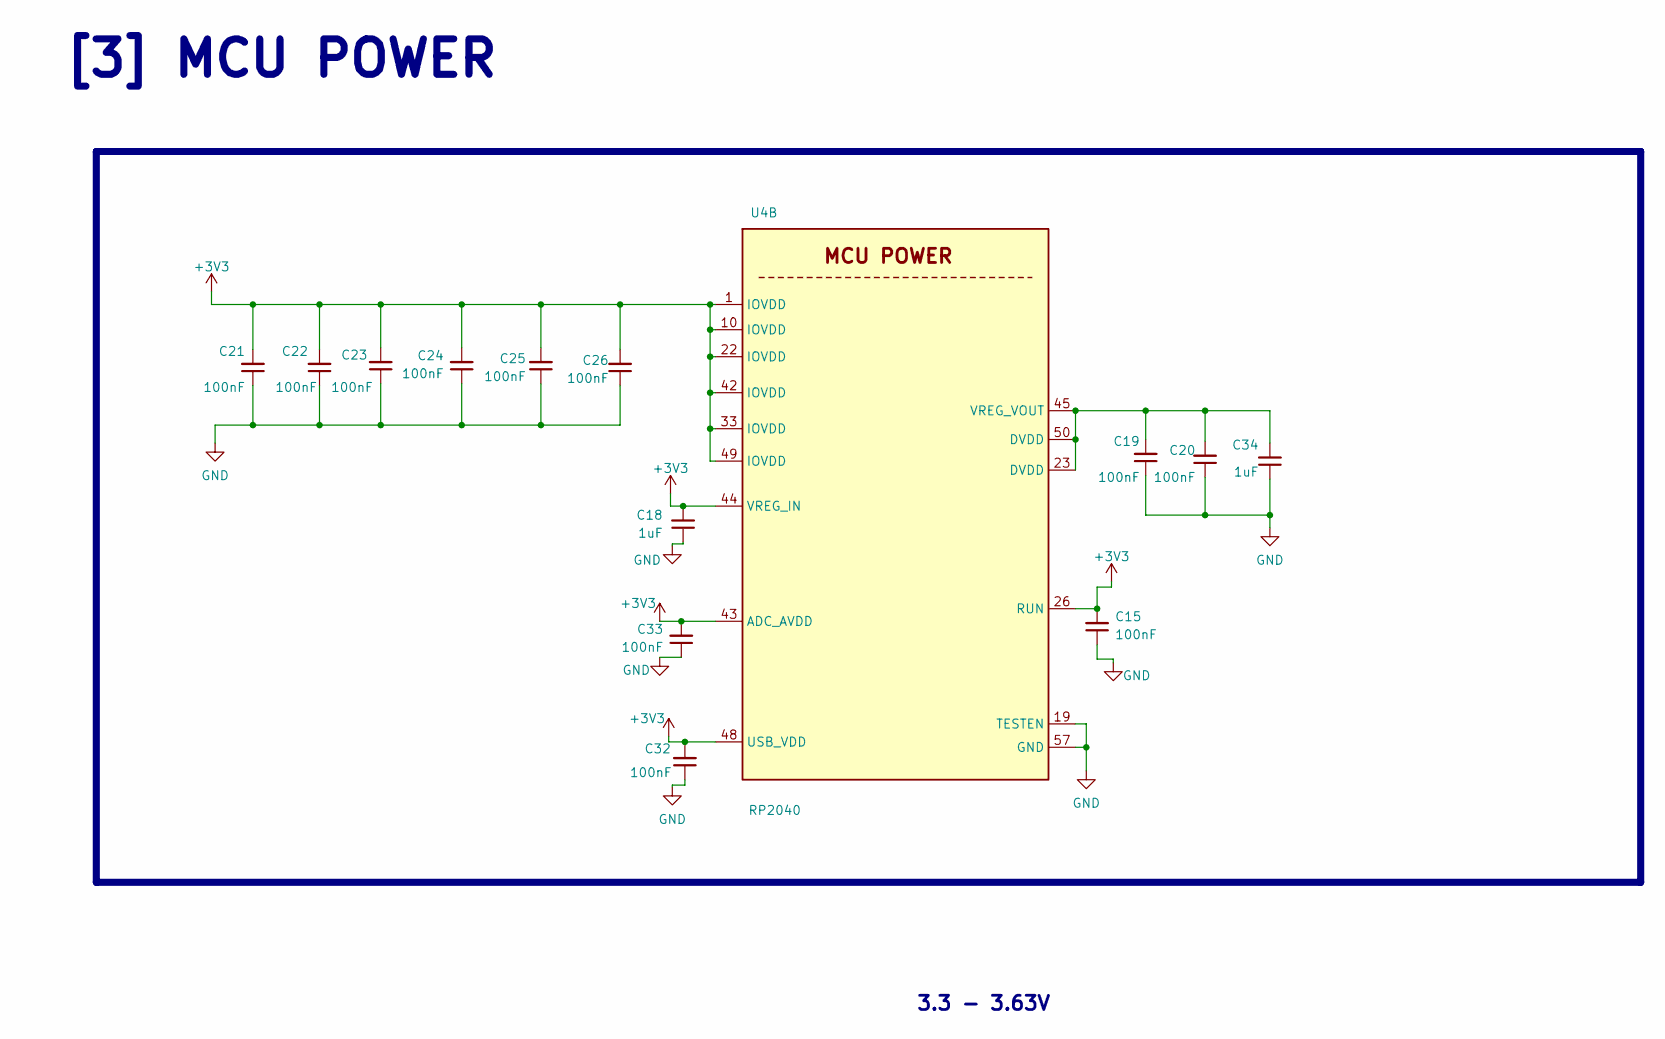
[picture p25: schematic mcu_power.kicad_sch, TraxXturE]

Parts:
C15, C19, C20, C21, C22, C23, C24, C25, C26, C32, C33: 100nF; C_0402_1005Metric
C18, C34: 1uF; C_0402_1005Metric
U4: RP2040; QFN-56-1EP_7x7mm_P0.4mm_EP3.2x3.2mm

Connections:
+3V3: C15.2, C18.2, C21.2, C22.2, C23.2, C24.2, C25.2, C26.2, C32.2, C33.2, U4.1 (IOVDD), U4.10 (IOVDD), U4.22 (IOVDD), U4.26 (RUN), U4.33 (IOVDD), U4.42 (IOVDD), U4.43 (ADC_AVDD), U4.44 (VREG_IN), U4.48 (USB_VDD), U4.49 (IOVDD); also elsewhere on the board
GND: C15.1, C18.1, C19.1, C20.1, C21.1, C22.1, C23.1, C24.1, C25.1, C26.1, C32.1, C33.1, C34.1, U4.19 (TESTEN), U4.57 (GND); also elsewhere on the board
unnamed: C19.2, C20.2, C34.2, U4.23 (DVDD), U4.45 (VREG_VOUT), U4.50 (DVDD)

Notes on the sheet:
[3] MCU POWER
3.3 - 3.63V

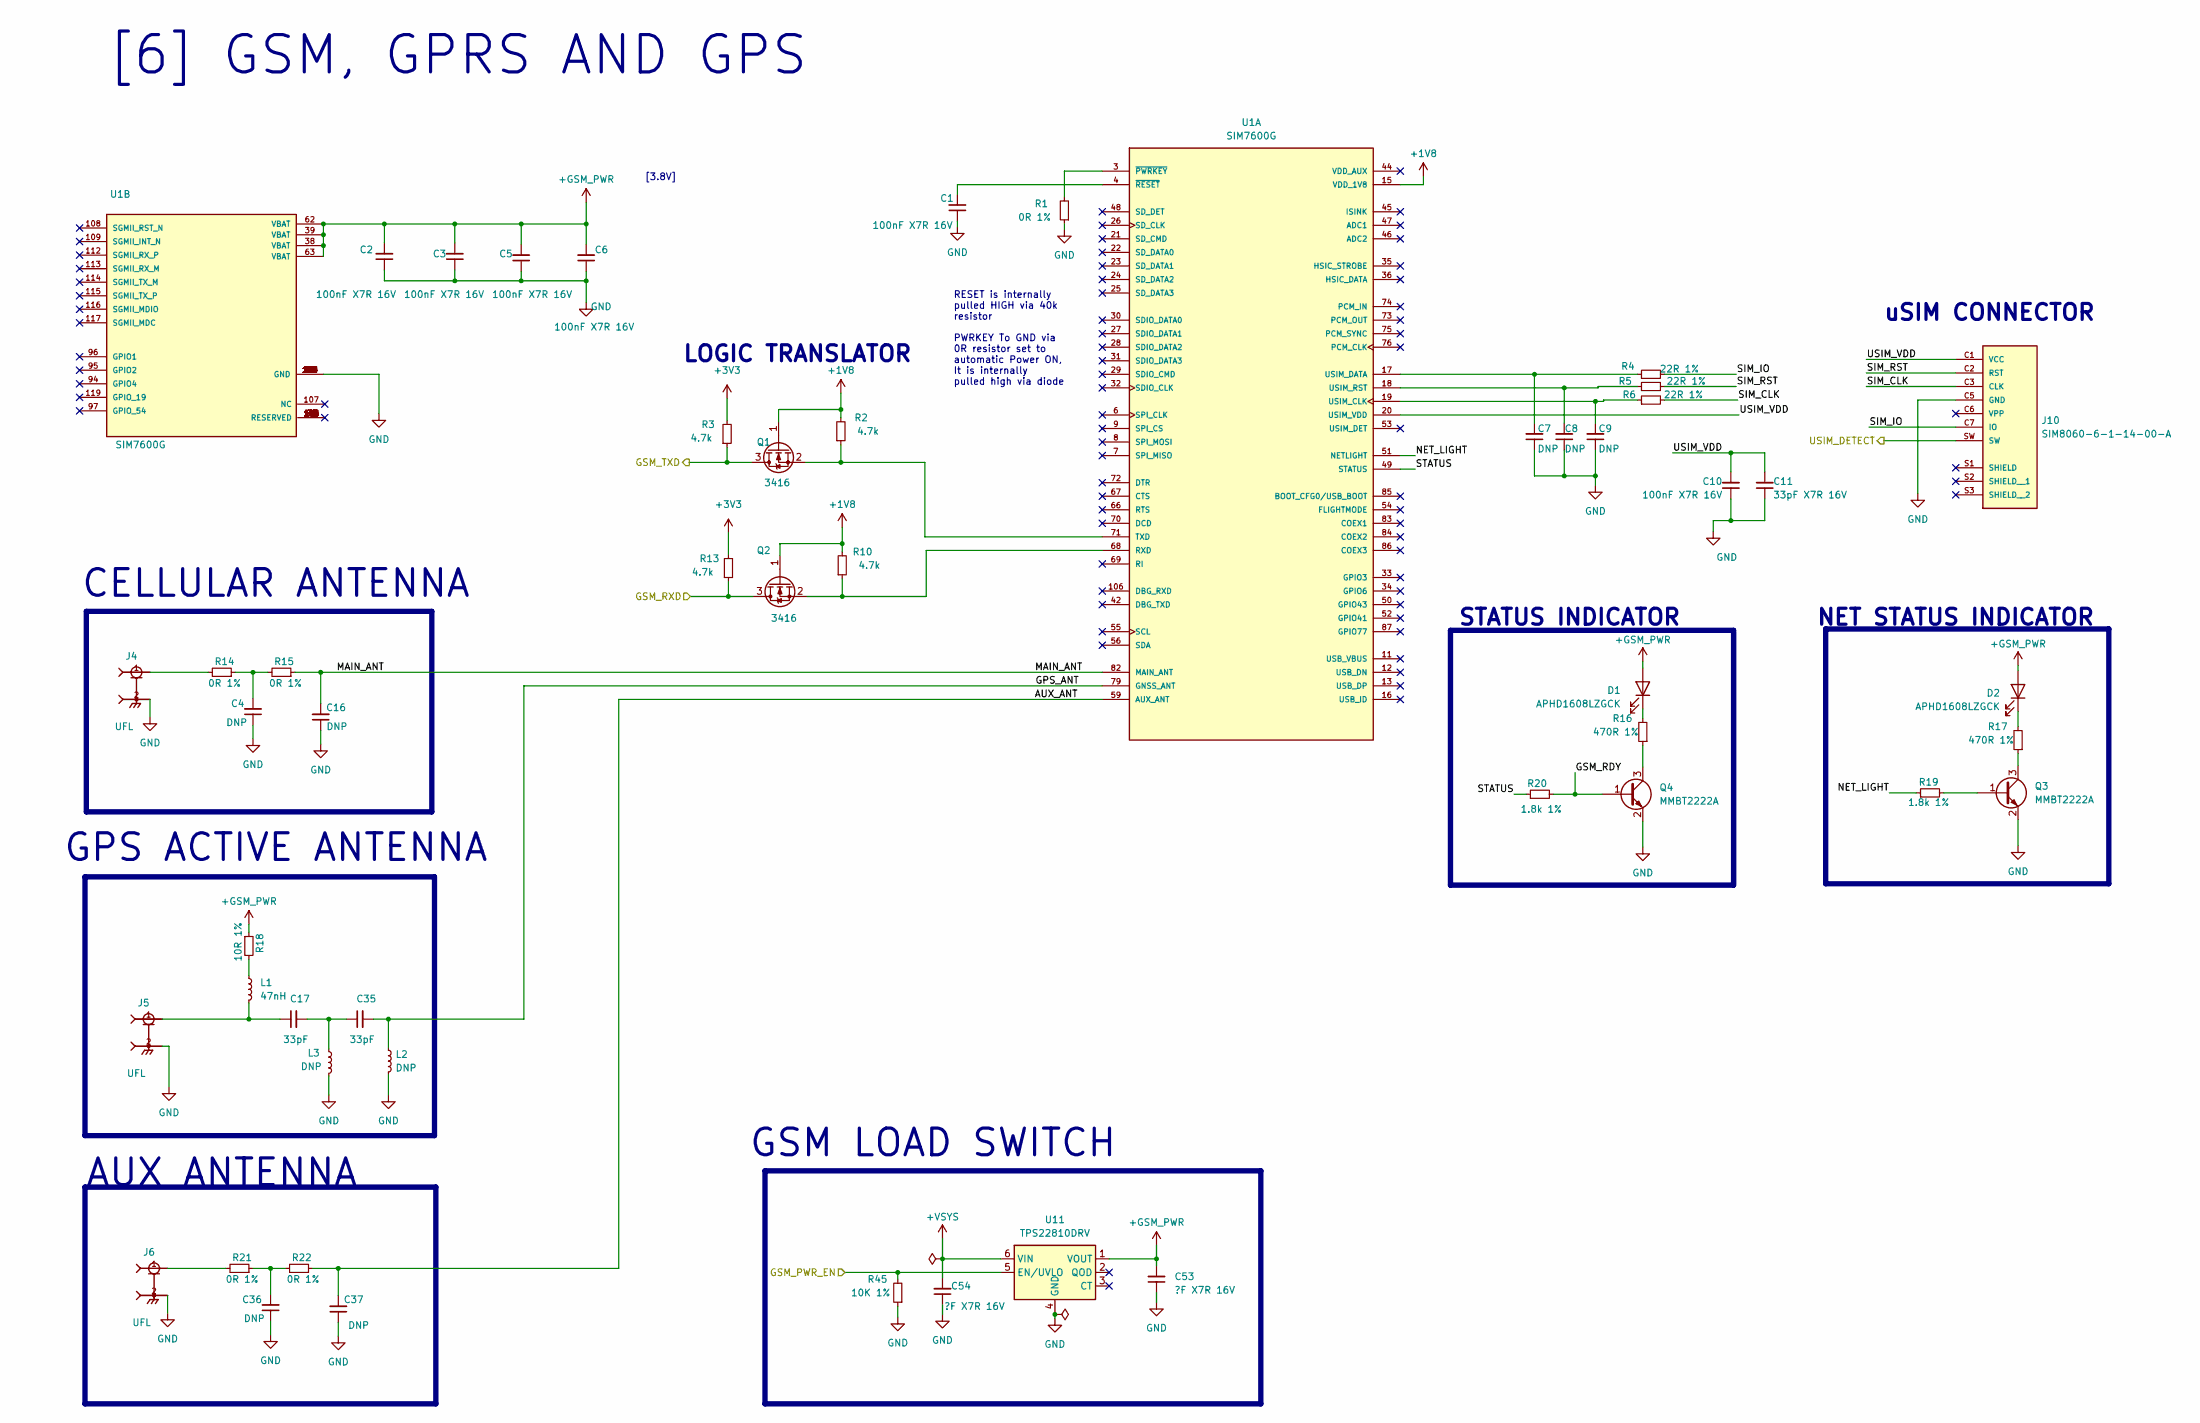
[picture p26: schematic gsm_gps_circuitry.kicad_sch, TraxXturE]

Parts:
C1, C2, C3, C5, C6, C10: 100nF X7R 16V; C_0402_1005Metric
C4, C16, C36, C37: DNP; C_0603_1608Metric
C7, C8, C9: DNP; C_0402_1005Metric
C11: 33pF X7R 16V; C_0402_1005Metric
C17, C35: 33pF; C_0603_1608Metric
C53, C54: ?F X7R 16V; C_0402_1005Metric
D1, D2: APHD1608LZGCK; LED_0603_1608Metric
J4, J5, J6: UFL; HRS_U.FL-R-SMT_10_
J10: SIM8060-6-1-14-00-A; GCT_SIM8060-6-1-14-00-A; PARTREV A
L1: 47nH; L_0603_1608Metric
L2, L3: DNP; L_0603_1608Metric
Q1, Q2: 3416; SOT-23
Q3, Q4: MMBT2222A; SOT-23
R1, R14, R15, R21, R22: 0R 1%; R_0402_1005Metric
R2, R3, R10, R13: 4.7k; R_0402_1005Metric
R4, R5, R6: 22R 1%; R_0402_1005Metric
R16, R17: 470R 1%; R_0402_1005Metric
R18: 10R 1%; R_0402_1005Metric
R19, R20: 1.8k 1%; R_0402_1005Metric
R45: 10K 1%; R_0402_1005Metric
U1: SIM7600G; IC_SIM7600G
U11: TPS22810DRV; WSON-6-1EP_2x2mm_P0.65mm_EP1x1.6mm

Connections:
+1V8: Q1.1 (G), Q2.1 (G), R2.2, R10.2, U1.15 (VDD_1V8)
+3V3: R3.2, R13.2; also elsewhere on the board
+GSM_PWR: C2.2, C3.2, C5.2, C6.2, C53.2, D1.2 (A), D2.2 (A), R18.1, U1.38 (VBAT), U1.39 (VBAT), U1.62 (VBAT), U1.63 (VBAT), U11.1 (VOUT)
+VSYS: C54.2, U11.6 (VIN); also elsewhere on the board
/Architectural_diagram/GSM_GPS_CIRCUITRY/AUX_ANT: C37.2, R22.1, U1.59 (AUX_ANT)
/Architectural_diagram/GSM_GPS_CIRCUITRY/GPS_ANT: C35.2, L2.1, U1.79 (GNSS_ANT)
/Architectural_diagram/GSM_GPS_CIRCUITRY/GSM_PWR_EN: R45.2, U11.5 (EN/UVLO); also elsewhere on the board
/Architectural_diagram/GSM_GPS_CIRCUITRY/GSM_RDY: Q4.1 (B), R20.2
/Architectural_diagram/GSM_GPS_CIRCUITRY/GSM_RXD: Q2.3 (D), R13.1; also elsewhere on the board
/Architectural_diagram/GSM_GPS_CIRCUITRY/GSM_TXD: Q1.3 (D), R3.1; also elsewhere on the board
/Architectural_diagram/GSM_GPS_CIRCUITRY/MAIN_ANT: C16.2, R15.1, U1.82 (MAIN_ANT)
/Architectural_diagram/GSM_GPS_CIRCUITRY/NET_LIGHT: R19.1, U1.51 (NETLIGHT)
/Architectural_diagram/GSM_GPS_CIRCUITRY/SIM_CLK: J10.C3 (CLK), R6.2
/Architectural_diagram/GSM_GPS_CIRCUITRY/SIM_IO: J10.C7 (IO), R4.2
/Architectural_diagram/GSM_GPS_CIRCUITRY/SIM_RST: J10.C2 (RST), R5.2
/Architectural_diagram/GSM_GPS_CIRCUITRY/STATUS: R20.1, U1.49 (STATUS)
/Architectural_diagram/GSM_GPS_CIRCUITRY/USIM_DETECT: J10.SW
/Architectural_diagram/GSM_GPS_CIRCUITRY/USIM_VDD: C10.2, C11.2, J10.C1 (VCC), U1.20 (USIM_VDD)
GND: C1.1, C2.1, C3.1, C4.1, C5.1, C6.1, C7.1, C8.1, C9.1, C10.1, C11.1, C16.1, C36.1, C37.1, C53.1, C54.1, J4.2, J5.2, J6.2, J10.C5 (GND), L2.2, L3.2, Q3.2 (E), Q4.2 (E), R1.1, R45.1, U1.1 (GND), U1.2 (GND), U1.5 (GND), U1.10 (GND), U1.14 (GND), U1.37 (GND), U1.40 (GND), U1.41 (GND), U1.43 (GND), U1.57 (GND), U1.58 (GND), U1.60 (GND), U1.61 (GND), U1.64 (GND), U1.65 (GND), U1.77 (GND), U1.78 (GND), U1.80 (GND), U1.81 (GND), U1.93 (GND), U1.98 (GND), U1.110 (GND), U1.118 (GND), U1.120 (GND), U1.121 (GND), U1.122 (GND), U1.123 (GND), U1.124 (GND), U1.125 (GND), U1.126 (GND), U1.127 (GND), U1.128 (GND), U1.129 (GND), U1.130 (GND), U1.131 (GND), U1.132 (GND), U1.133 (GND), U1.134 (GND), U1.135 (GND), U11.4 (GND), U11.7 (GND); also elsewhere on the board
unnamed: C4.2, R14.1, R15.2
unnamed: C17.1, J5.1, L1.2
unnamed: C17.2, C35.1, L3.1
unnamed: C36.2, R21.1, R22.2
unnamed: D1.1 (K), R16.2
unnamed: D2.1 (K), R17.2
unnamed: J4.1, R14.2
unnamed: J6.1, R21.2
unnamed: L1.1, R18.2
unnamed: Q1.2 (S), R2.1, U1.71 (TXD)
unnamed: Q2.2 (S), R10.1, U1.68 (RXD)
unnamed: Q3.1 (B), R19.2
unnamed: Q3.3 (C), R17.1
unnamed: Q4.3 (C), R16.1
unnamed: C9.2, R6.1, U1.19 (USIM_CLK)
unnamed: C7.2, R4.1, U1.17 (USIM_DATA)
unnamed: C8.2, R5.1, U1.18 (USIM_RST)
unnamed: R1.2, U1.3 (~PWRKEY)
unnamed: C1.2, U1.4 (~RESET)

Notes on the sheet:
RESET is internally pulled HIGH via 40k resistor
PWRKEY To GND via 0R resistor set to automatic Power ON, It is internally pulled high via diode
[6] GSM, GPRS AND GPS
CELLULAR ANTENNA
STATUS INDICATOR
NET STATUS INDICATOR
GSM LOAD SWITCH
uSIM CONNECTOR
GPS ACTIVE ANTENNA
AUX ANTENNA
LOGIC TRANSLATOR
[3.8V]

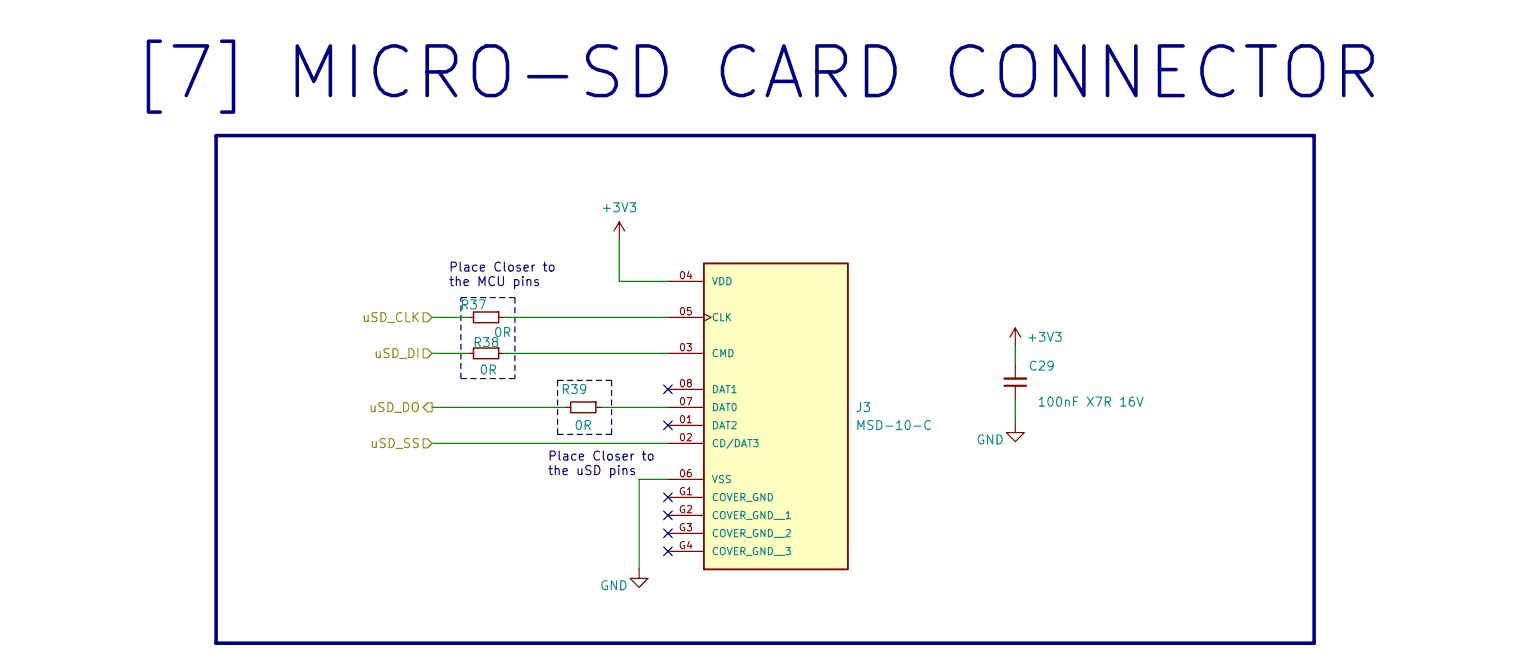
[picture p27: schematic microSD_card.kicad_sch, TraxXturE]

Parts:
C29: 100nF X7R 16V; C_0402_1005Metric
J3: MSD-10-C; CUI_MSD-10-C; PARTREV 1.0
R37, R38, R39: 0R; R_0402_1005Metric

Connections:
+3V3: C29.2, J3.04 (VDD); also elsewhere on the board
/Architectural_diagram/MCU_GPIO/SPI1_CSn: J3.02 (CD/DAT3); also elsewhere on the board
/Architectural_diagram/MCU_GPIO/SPI1_RX: R38.2; also elsewhere on the board
/Architectural_diagram/MCU_GPIO/SPI1_SCK: R37.2; also elsewhere on the board
/Architectural_diagram/MCU_GPIO/SPI1_TX: R39.2; also elsewhere on the board
GND: C29.1, J3.06 (VSS); also elsewhere on the board
unnamed: J3.05 (CLK), R37.1
unnamed: J3.03 (CMD), R38.1
unnamed: J3.07 (DAT0), R39.1

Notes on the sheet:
Place Closer to the uSD pins
Place Closer to the MCU pins
[7] MICRO-SD CARD CONNECTOR

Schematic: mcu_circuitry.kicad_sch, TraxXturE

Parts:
C12: 100nF; C_0402_1005Metric
C13, C14: 15pF; C_0402_1005Metric
J1: Conn_01x06; PinHeader_2x03_P2.54mm_Vertical
R9: 1k; R_0402_1005Metric
U3: W25Q128JVS; SOIC-8_5.23x5.23mm_P1.27mm
U4: RP2040; QFN-56-1EP_7x7mm_P0.4mm_EP3.2x3.2mm
Y1: ABM8-272-T3; ABM8-272-T3_ABR

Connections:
+3V3: C12.2, J1.1, U3.8 (VCC); also elsewhere on the board
/Architectural_diagram/GSM_GPS_CIRCUITRY/GSM_PWR_EN: U4.29 (GPIO18); also elsewhere on the board
/Architectural_diagram/IMU_Sensor/MPU_INT: U4.30 (GPIO19); also elsewhere on the board
/Architectural_diagram/IMU_Sensor/MPU_SCL: U4.17 (GPIO14); also elsewhere on the board
/Architectural_diagram/IMU_Sensor/MPU_SDA: U4.16 (GPIO13); also elsewhere on the board
/Architectural_diagram/Ignition_shutdown/IGN_DOWN: U4.38 (GPIO26_ADC0); also elsewhere on the board
/Architectural_diagram/MCU_GPIO/GPIO12: U4.15 (GPIO12); also elsewhere on the board
/Architectural_diagram/MCU_GPIO/GPIO20: U4.31 (GPIO20); also elsewhere on the board
/Architectural_diagram/MCU_GPIO/GPIO21: U4.32 (GPIO21); also elsewhere on the board
/Architectural_diagram/MCU_GPIO/GPIO23: U4.35 (GPIO23); also elsewhere on the board
/Architectural_diagram/MCU_GPIO/SPI0_CSn: U4.3 (GPIO1); also elsewhere on the board
/Architectural_diagram/MCU_GPIO/SPI0_RX: U4.2 (GPIO0); also elsewhere on the board
/Architectural_diagram/MCU_GPIO/SPI0_SCK: U4.4 (GPIO2); also elsewhere on the board
/Architectural_diagram/MCU_GPIO/SPI0_TX: U4.5 (GPIO3); also elsewhere on the board
/Architectural_diagram/MCU_GPIO/SPI1_CSn: U4.12 (GPIO9); also elsewhere on the board
/Architectural_diagram/MCU_GPIO/SPI1_RX: U4.11 (GPIO8); also elsewhere on the board
/Architectural_diagram/MCU_GPIO/SPI1_SCK: U4.13 (GPIO10); also elsewhere on the board
/Architectural_diagram/MCU_GPIO/SPI1_TX: U4.14 (GPIO11); also elsewhere on the board
/Architectural_diagram/MCU_GPIO/SWCLK: J1.2, U4.24 (SWCLK)
/Architectural_diagram/MCU_GPIO/SWD: J1.3, U4.25 (SWD)
/Architectural_diagram/MCU_GPIO/UART0_RX: J1.4, U4.28 (GPIO17)
/Architectural_diagram/MCU_GPIO/UART0_TX: J1.5, U4.27 (GPIO16)
/Architectural_diagram/MCU_GPIO/UART1_RX: U4.37 (GPIO25); also elsewhere on the board
/Architectural_diagram/MCU_GPIO/UART1_TX: U4.36 (GPIO24); also elsewhere on the board
GND: C12.1, C13.1, C14.1, J1.6, U3.4 (GND), Y1.2, Y1.4; also elsewhere on the board
unnamed: C13.2, R9.1, Y1.3
unnamed: U3.6 (CLK), U4.52 (QSPI_SCLK)
unnamed: U3.5 (DI(IO0)), U4.53 (QSPI_SD0)
unnamed: U3.2 (DO(IO1)), U4.55 (QSPI_SD1)
unnamed: U3.3 (IO2), U4.54 (QSPI_SD2)
unnamed: U3.7 (IO3), U4.51 (QSPI_SD3)
unnamed: U3.1 (~CS), U4.56 (QSPI_SS)
unnamed: C14.2, U4.20 (XIN), Y1.1
unnamed: R9.2, U4.21 (XOUT)

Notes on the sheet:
EXTERNAL FLASH MEMORY
DEBUG/PROG
[4] MCU GPIO

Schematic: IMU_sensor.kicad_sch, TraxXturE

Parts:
C27, C31: 100nF X7R 16V; C_0402_1005Metric
C28: 2.2nF X7R 16V; C_0402_1005Metric
JP1: jumper; SolderJumper-3_P1.3mm_Bridged12_RoundedPad1.0x1.5mm
R12: 10k; R_0402_1005Metric
U5: MPU-6050; InvenSense_QFN-24_4x4mm_P0.5mm

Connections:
+3V3: C31.2, JP1.3 (B), R12.2, U5.8 (VLOGIC), U5.13 (VDD); also elsewhere on the board
/Architectural_diagram/IMU_Sensor/MPU_CPOUT: C28.2, U5.20 (CPOUT)
/Architectural_diagram/IMU_Sensor/MPU_INT: R12.1, U5.12 (INT); also elsewhere on the board
/Architectural_diagram/IMU_Sensor/MPU_REGOUT: C27.2, U5.10 (REGOUT)
/Architectural_diagram/IMU_Sensor/MPU_SCL: U5.23 (SCL); also elsewhere on the board
/Architectural_diagram/IMU_Sensor/MPU_SDA: U5.24 (SDA); also elsewhere on the board
GND: C27.1, C28.1, C31.1, JP1.1 (A), U5.1 (CLKIN), U5.11 (FSYNC), U5.18 (GND); also elsewhere on the board
unnamed: JP1.2 (C), U5.9 (AD0)

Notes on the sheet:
AD0 (HIGH): 1101001
[8] IMU CIRCUITRY
AD0 (LOW): 1101000

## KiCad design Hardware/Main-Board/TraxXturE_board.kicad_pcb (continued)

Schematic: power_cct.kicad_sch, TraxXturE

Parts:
BT1: 18650 holder; SolderWire-0.1sqmm_1x02_P3.6mm_D0.4mm_OD1mm
C38: 47nF; C_0402_1005Metric
C39: 4.7uF; C_0603_1608Metric
C40, C42: 1uF; C_0603_1608Metric
C41: 2.2uF; C_0402_1005Metric
C43: 10uF X7R; C_0805_2012Metric
C44: 4.7uF; C_0805_2012Metric
C45: 10uF; C_0603_1608Metric
C46, C47, C48: 10uF; C_0805_2012Metric
C49: 100nF; C_0402_1005Metric
C55: 22uF; C_0603_1608Metric
D3: APHD1608LZGCK; LED_0603_1608Metric
D5: SZMMSZ5250BT1G; D_SOD-123
J7: Conn_01x02; TE_440055-2_1x02_P2.00mm_Horizontal
L4: MDA4020-1R0M; L_Wurth_WE-LQSH-4020
L5: VLS3012CX-2R2M-1; IND_VLS3012CX-2R2M-1
Q5: MGSF1N02LT1G; SOT-23
Q7: IPD90P03P4L-04-HXY; TO-252-2
Q8: CJ3401; SOT-23
Q9, Q10: AO3400A; SOT-23
R23: 24R; R_0603_1608Metric
R24: 5mR 1% 1watt; R_0805_2012Metric
R25: 10k 1%; R_0402_1005Metric
R26: 470R; R_0402_1005Metric
R27, R28, R29: 10k; R_0402_1005Metric
R30: 100R; R_0402_1005Metric
R31: 590k; R_0402_1005Metric
R32, R47, R48: 100k; R_0402_1005Metric
R46: 1k; R_0402_1005Metric
R49: 220k; R_0402_1005Metric
R50: 330k; R_0402_1005Metric
SW1: TL3330AF260QG; SW_TL3330AF260QG
U2: bq34210-Q1; TSSOP-14_4.4x5mm_P0.65mm
U6: BQ25601; Texas_RTW_WQFN-24-1EP_4x4mm_P0.5mm_EP2.7x2.7mm_ThermalVias
U7: TPS63000; Texas_DRC0010J_ThermalVias

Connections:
+3V3: C47.2, C48.2, R31.1, U7.1 (VOUT); also elsewhere on the board
+VBATT: BT1.1 (+), C42.2, R24.2, U2.5 (REGIN), U2.10 (SRP)
+VSYS: C39.2, C46.2, D3.2 (A), L4.1, R30.2, U6.15 (SYS), U6.16 (SYS), U7.5 (VIN); also elsewhere on the board
/Architectural_diagram/IMU_Sensor/MPU_SCL: U2.2 (SCL), U6.5 (SCL); also elsewhere on the board
/Architectural_diagram/IMU_Sensor/MPU_SDA: U2.1 (SDA), U6.6 (SDA); also elsewhere on the board
/Architectural_diagram/MCU_GPIO/GPIO12: Q5.1 (G); also elsewhere on the board
/Architectural_diagram/MCU_GPIO/GPIO20: U2.14 (ALERT); also elsewhere on the board
/Architectural_diagram/MCU_GPIO/GPIO21: U6.7 (~INT); also elsewhere on the board
/Architectural_diagram/MCU_GPIO/GPIO23: U6.9 (~CE); also elsewhere on the board
/Architectural_diagram/Power_circuitry/BB_FB: R31.2, R32.1, U7.10 (FB)
/Architectural_diagram/Power_circuitry/BG_TS: R25.1, U2.12 (TS)
/Architectural_diagram/Power_circuitry/BMS_PMID: C45.2, U6.23 (PMID)
/Architectural_diagram/Power_circuitry/BMS_PSEL: R28.1, U6.2 (PSEL)
/Architectural_diagram/Power_circuitry/BMS_TS: R27.2, R29.1, U6.11 (TS)
/Architectural_diagram/Power_circuitry/P3V3_SW1: L5.1, U7.4 (L1)
/Architectural_diagram/Power_circuitry/P3V3_SW2: L5.2, U7.2 (L2)
/Architectural_diagram/Power_circuitry/PP_SW: C38.2, L4.2, U6.19 (SW), U6.20 (SW)
/Architectural_diagram/Power_circuitry/REGN: C44.2, R27.1, U6.22 (REGN)
/Architectural_diagram/Power_circuitry/Vin: J7.1, Q7.3 (D)
/Architectural_diagram/Power_circuitry/Vin_2: C40.2, D5.1 (K), Q7.2 (S), U6.1 (VAC), U6.24 (VBUS)
GND: BT1.2 (-), C39.1, C40.1, C41.1, C42.1, C43.1, C44.1, C45.1, C46.1, C47.1, C48.1, C49.1, C55.1, J7.2, Q5.2 (S), Q9.2 (S), Q10.2 (S), R25.2, R28.2, R29.2, R32.2, R46.1, U2.3 (VSS), U6.17 (GND), U6.18 (GND), U6.25 (GND), U7.3 (PGND), U7.9 (GND), U7.11 (PGND); also elsewhere on the board
unnamed: D3.1 (K), R26.2
unnamed: D5.2 (A), Q7.1 (G), R46.2
unnamed: Q5.3 (D), R23.2
unnamed: Q8.1 (G), Q9.3 (D), R47.2
unnamed: Q9.1 (G), R49.2, SW1.1
unnamed: Q10.3 (D), R48.2, SW1.2
unnamed: C55.2, Q10.1 (G), R50.2
unnamed: C38.1, U6.21 (BTST)
unnamed: R26.1, U6.4 (STAT)
unnamed: C49.2, R30.1, U7.6 (EN), U7.7 (PS/SYNC), U7.8 (VINA)
PACK+: Q8.2 (S), R23.1, R24.1, R47.1, R48.1, U2.9 (SRN)
PACK_OUT+: C43.2, Q8.3 (D), R49.1, R50.1, U6.13 (BAT), U6.14 (BAT)

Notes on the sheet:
Recommended discharge current level from Ref manual below is C/20, pg24 sub-heading 1.3.34 https://www.ti.com/lit/ug/sluube8/sluube8.pdf?ts=1735472964646
Ensure SDA, SCL, INT are pull to high(to MCU power level)
The output voltage is 3.45V, to compensate for the voltage accross the camera communication bus.
[5] POWER CIRCUITRY
PUSH-ON/OFF
7-13.5Vdc
POWERPATH, BMS
CHARGE STATUS: * ON: IN PROGRESS * OFF: CHG COMPLETE/SLEEP mode * 1Hz pulse: Fault response the pins can be disable via EN_ICH_MON[1:0] register to hide noticeable light
+3V3 BUCK-BOOST
BATTERY GUAGE

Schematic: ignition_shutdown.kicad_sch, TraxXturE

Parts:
D4: M7; D_SMA
J9: Conn_01x02; TE_440055-2_1x02_P2.00mm_Horizontal
K1: A161CS12VDC.64; RELAY_A161CS12VDC_64; PARTREV B
Q6: MMBT2222A; SOT-23
R11: 910R; R_0402_1005Metric

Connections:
+12V: D4.1 (K), K1.A2
/Architectural_diagram/Ignition_shutdown/IGN_COM: J9.2, K1.COM
/Architectural_diagram/Ignition_shutdown/IGN_DOWN: R11.1; also elsewhere on the board
/Architectural_diagram/Ignition_shutdown/IGN_NC: J9.1, K1.NC
GND: Q6.2 (E); also elsewhere on the board
unnamed: D4.2 (A), K1.A1, Q6.3 (C)
unnamed: Q6.1 (B), R11.2

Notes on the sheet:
[11] IGNITION SHUTDOWN CIRCUITRY

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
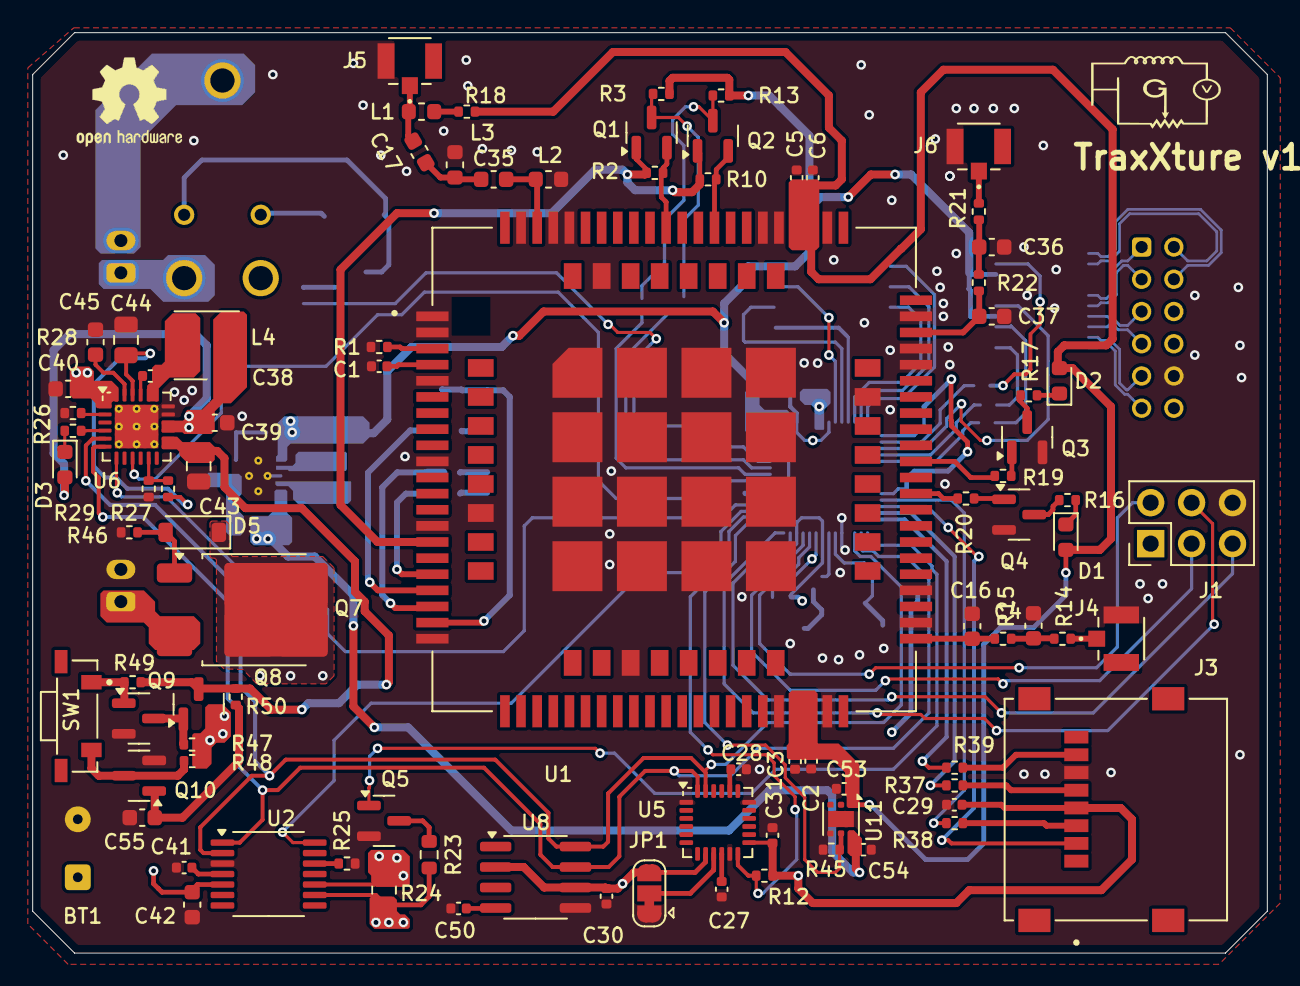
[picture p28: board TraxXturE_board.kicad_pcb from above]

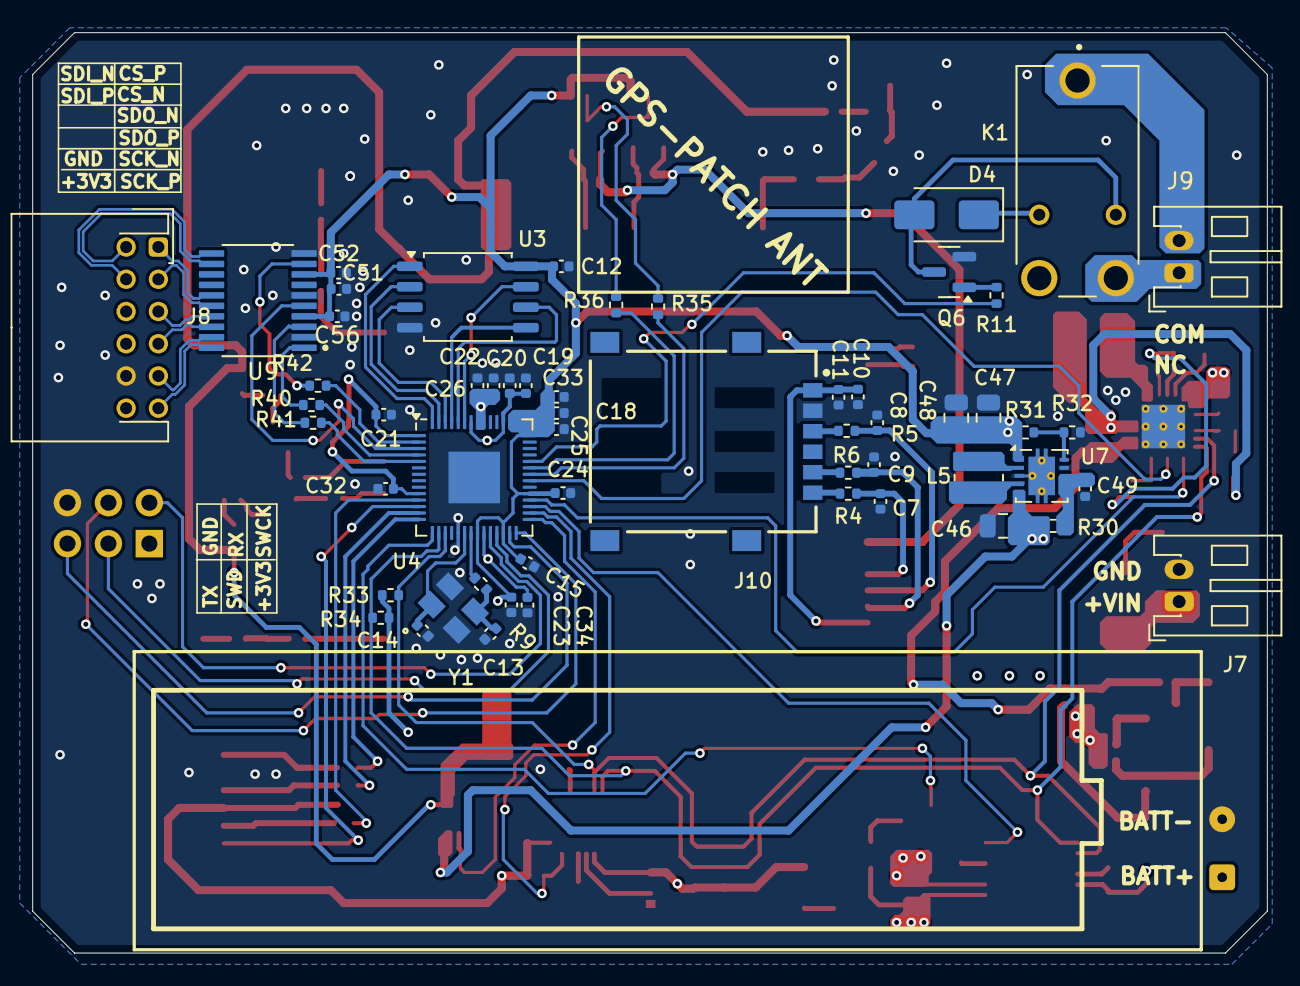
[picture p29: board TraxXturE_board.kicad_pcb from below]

Board: 4 copper layers, 76.6 x 57.1 mm, 146 parts (56 on the bottom side), 117 nets.

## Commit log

2025-02-11 Done with main board design, and camera interconnect in progress
    [Cam_interconnect.kicad_pcb, Cam_interconnect.kicad_sch, IMU_sensor.kicad_sch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]
2025-02-11 Updated the pdf for main board schematics
    [Cam_interconnect.kicad_sch, camera_pinouts.kicad_sch]
